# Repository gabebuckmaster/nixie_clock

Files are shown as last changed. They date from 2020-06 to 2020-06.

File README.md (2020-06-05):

# Nixie Tube Clock

<p align="center">
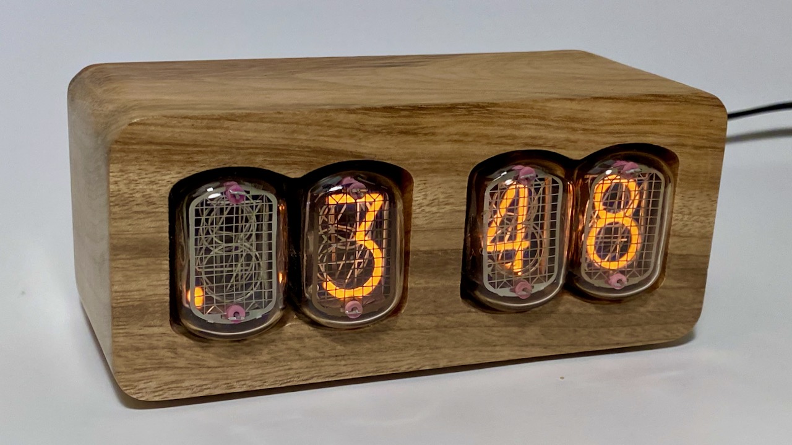
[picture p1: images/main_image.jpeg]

</p>

A minimalist nixie tube clock design in a cnc-machined hardwood case using IN12B tubes.

All of the design files and detailed assembly/compilation instructions for the electronics, mechanical components, and firmware can be found in the respective subfolders: <a href=electronics>Electronics</a>, <a href=mechanical>Mechanical</a>, and <a href=firmware>Firmware</a>. 

This design has gone through several iterations, mostly to simplify the design and remove extraneous features that I thought would be a good idea but ultimately weren't. While nixie tubes are beautiful, they objectively have some significant shortcomings as a display technology: their viewing angle is extremely limited, and they can't be dimmed to arbitrarily low brightnesses - not to mention the difficulty in working with the high voltages needed to drive them. Over the course of the project, the goal converged to showing off the beauty of nixie tubes with the minimum possible set of features, and I'm happy with how the final result aligns with this goal.

I learned a lot about cnc machining, and am left with a great respect for the people who do this for a living. An incredible amount of effort (and skill among those who practice this professionally) goes into simply clamping the work piece in a way that allows the router/mill the necessary access. I also learned a lot about boost converter design, specifically core losses, the huge range of magnetic core materials, and why power electronics people often advise against designing boost converters that operate in DCM.

## License and Disclaimer
I built this clock because I wanted it to exist, and I’m distributing the documentation in the hopes that others find it interesting and/or educational. To this end, the files provided in this repository are licensed under the MIT license unless otherwise noted a given file.

This design is not FCC, CE, or UL certified, and thus it is probably not legal nor advisable to sell this design as a finished product in your jurisdiction. This project involves potentially dangerous power tools, potentially lethal voltages, and potential fire hazard due to housing electronics in a flammable material. **If you choose to recreate any work documented in this repository, you do so entirely at your own risk.**

## Final Assembly
The bill of materials for the final assembly is in <a href="final_assembly_bom.csv">Final Assembly BOM</a>.

### Pseudo-exploded view of the final assembly
<p align="center">
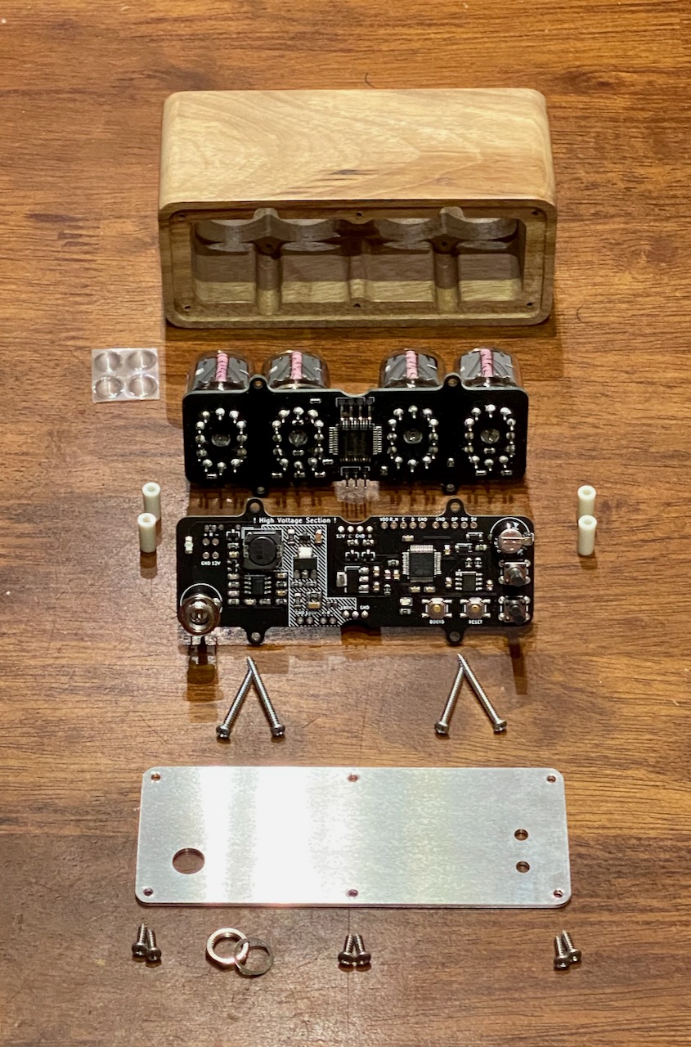
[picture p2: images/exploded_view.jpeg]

</p>

### Video of final assembly
<p align="center">
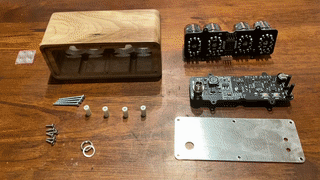
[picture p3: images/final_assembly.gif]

</p>
Click through for longer/higher resolution video of final assembly.

## More Photos
### Final Assembly
<p align="center">
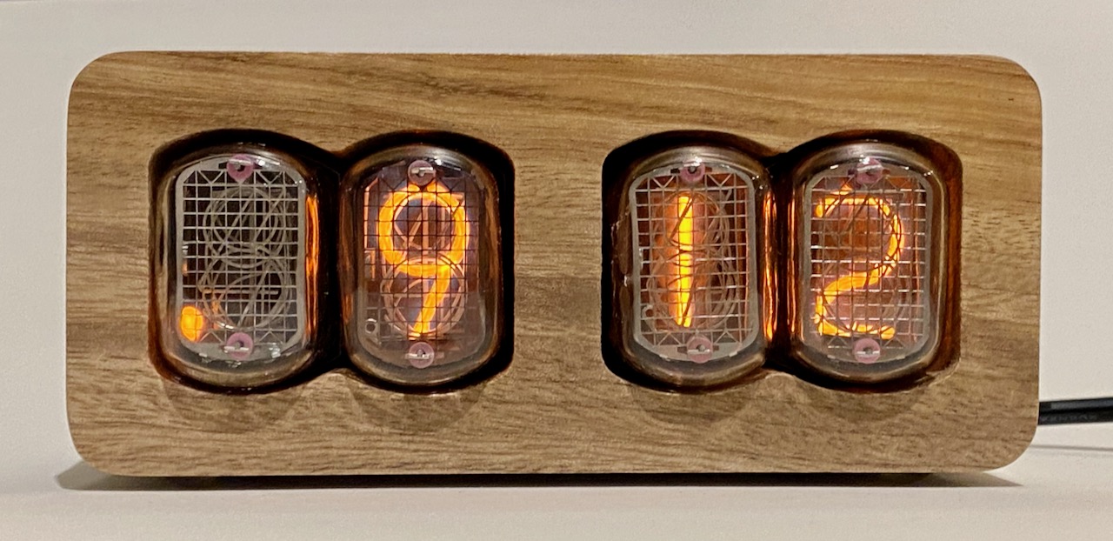
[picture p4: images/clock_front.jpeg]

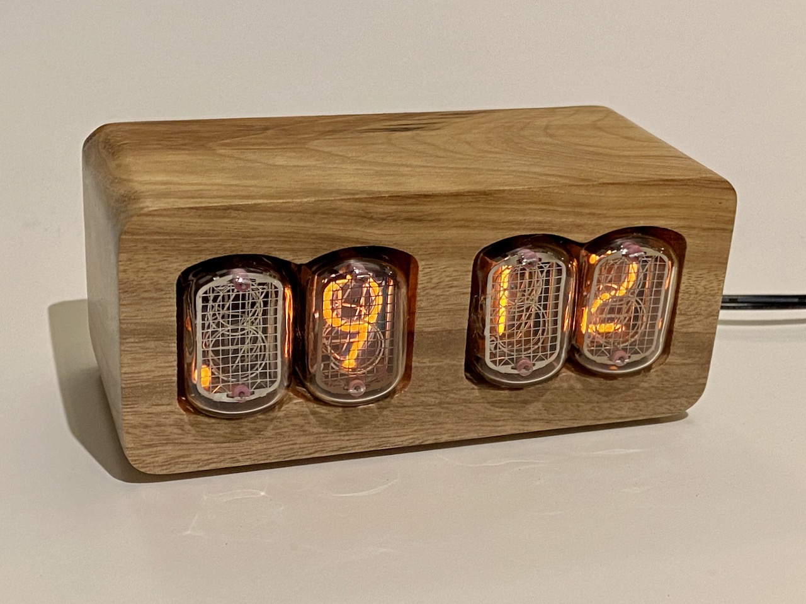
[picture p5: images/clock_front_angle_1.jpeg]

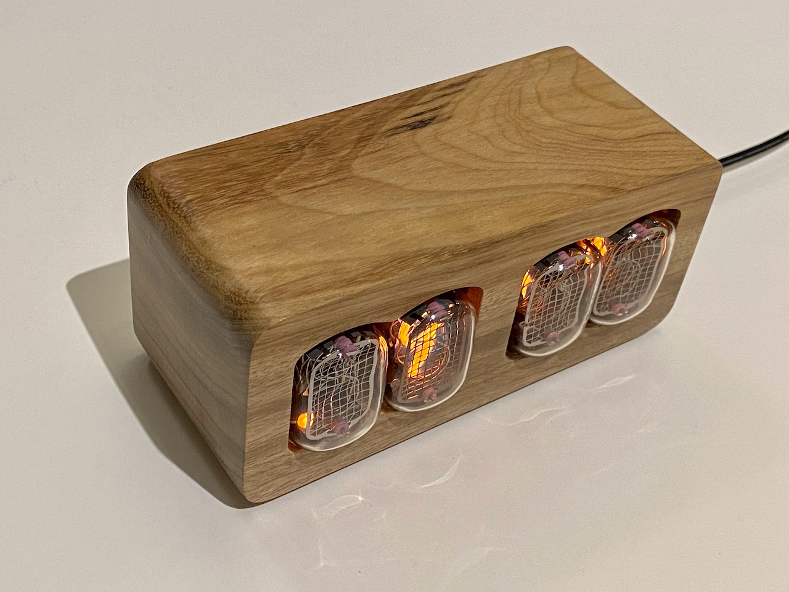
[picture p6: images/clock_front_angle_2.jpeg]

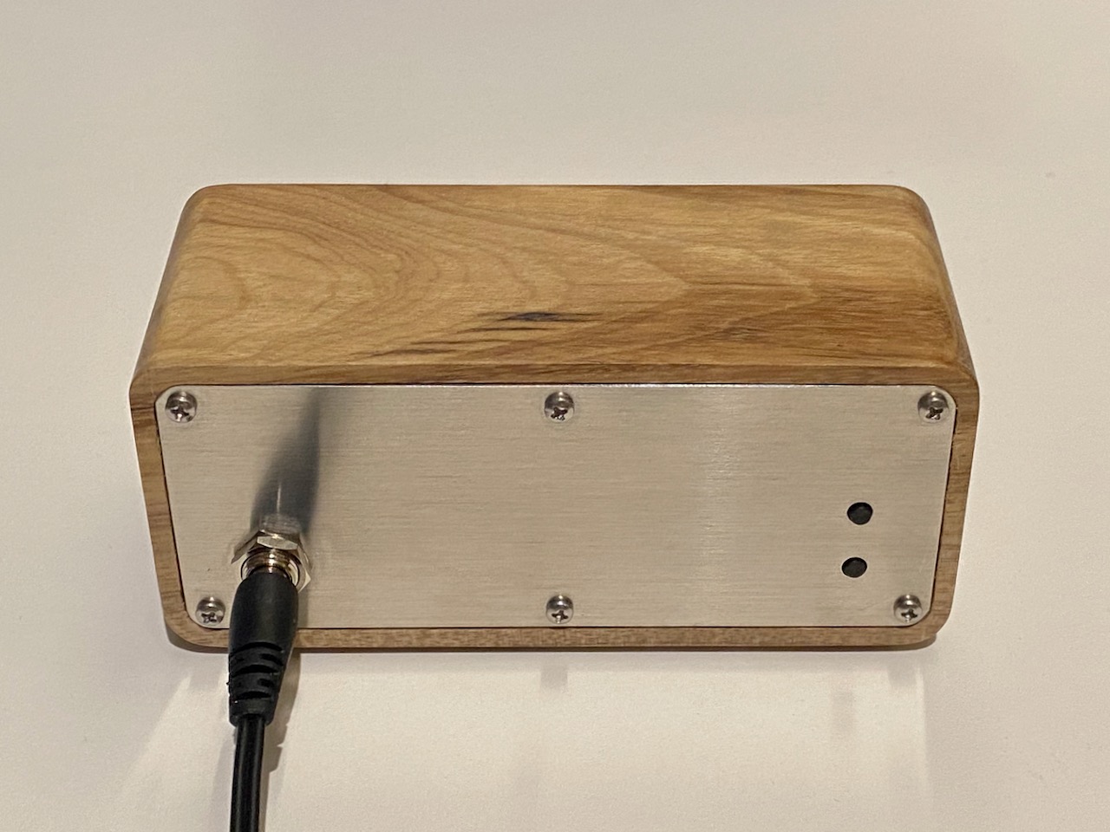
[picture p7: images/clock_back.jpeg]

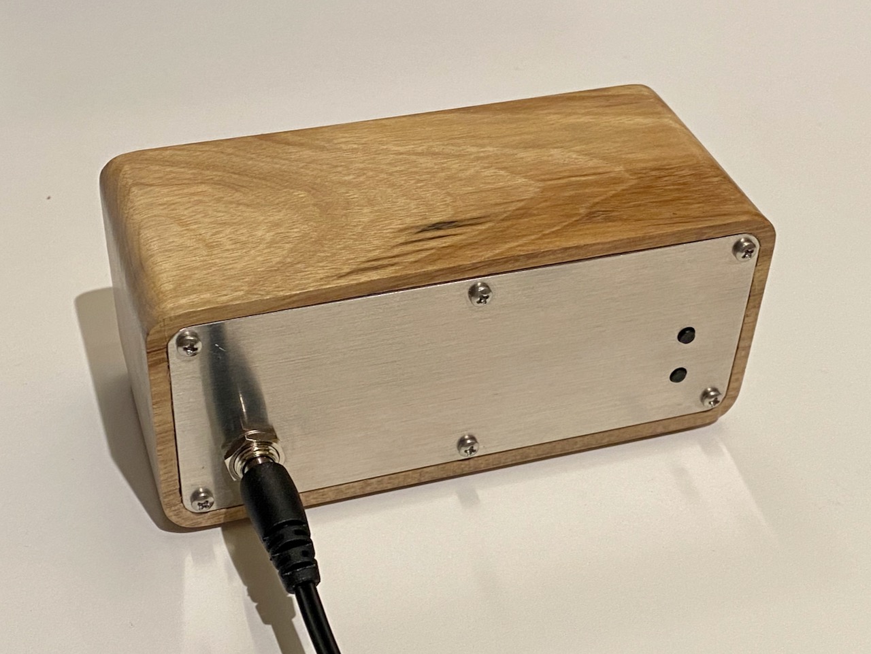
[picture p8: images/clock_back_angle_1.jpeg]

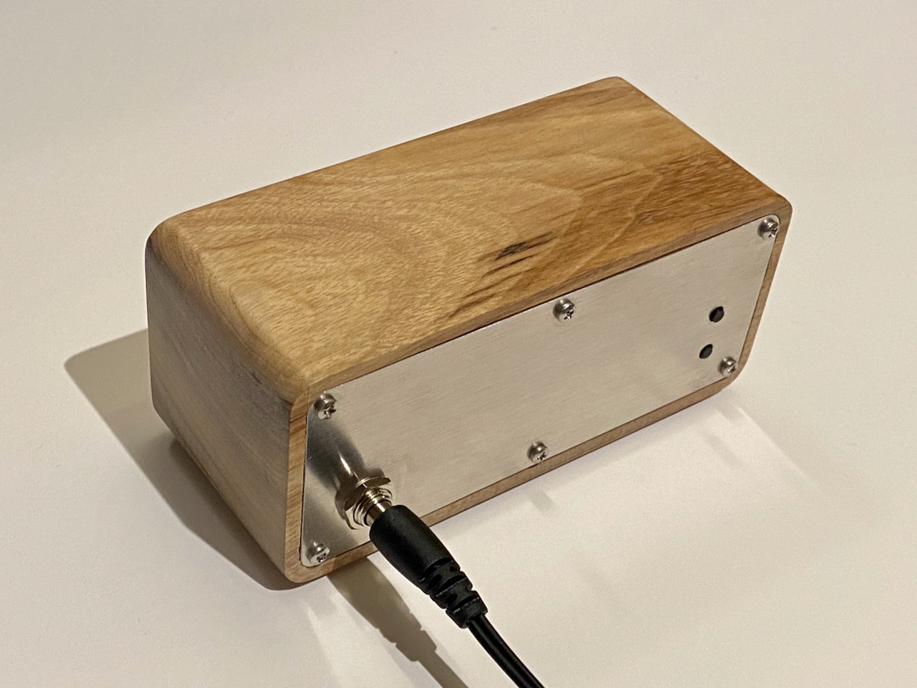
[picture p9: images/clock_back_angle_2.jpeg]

</p>

### Electronics
<p align="center">
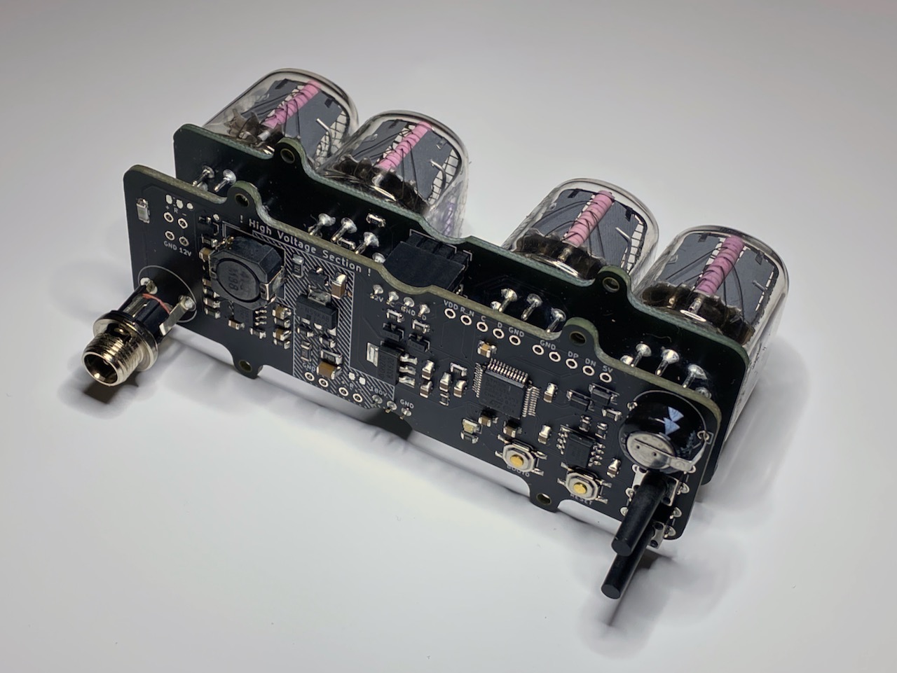
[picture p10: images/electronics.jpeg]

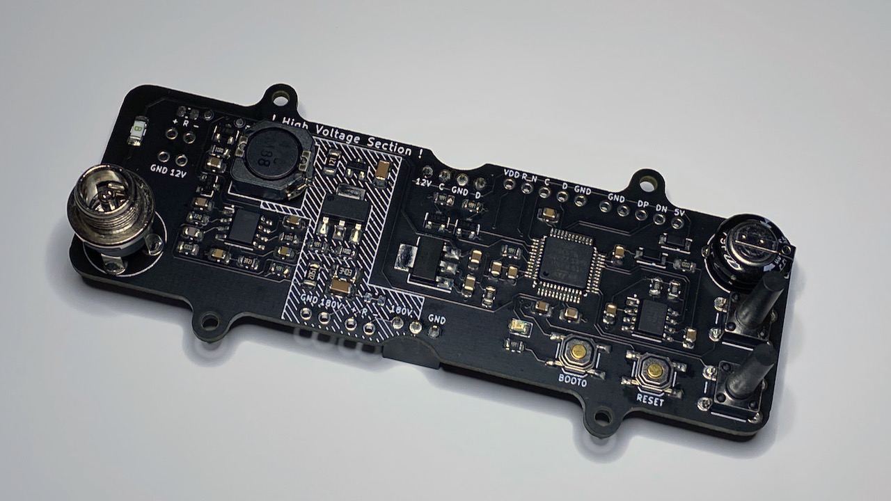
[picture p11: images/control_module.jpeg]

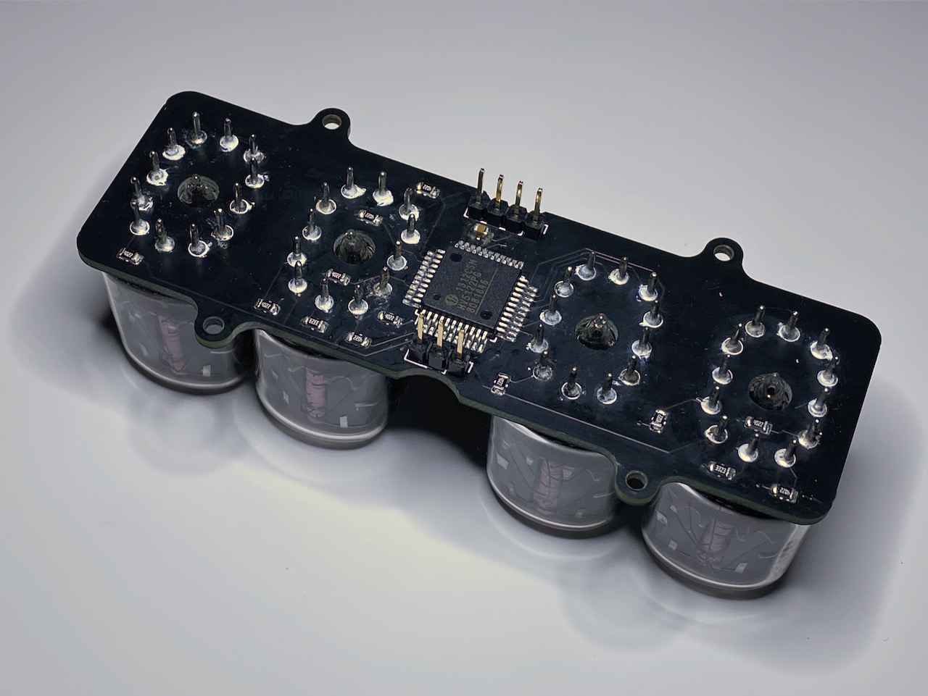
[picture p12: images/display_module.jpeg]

</p>

### Clock Body
<p align="center">
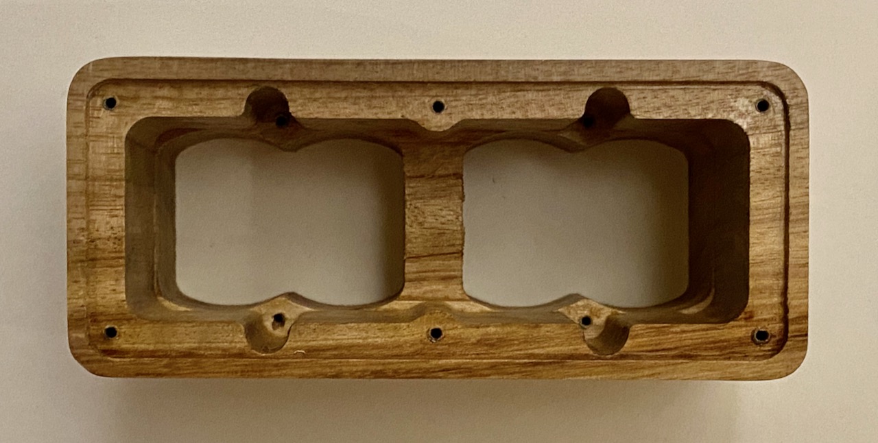
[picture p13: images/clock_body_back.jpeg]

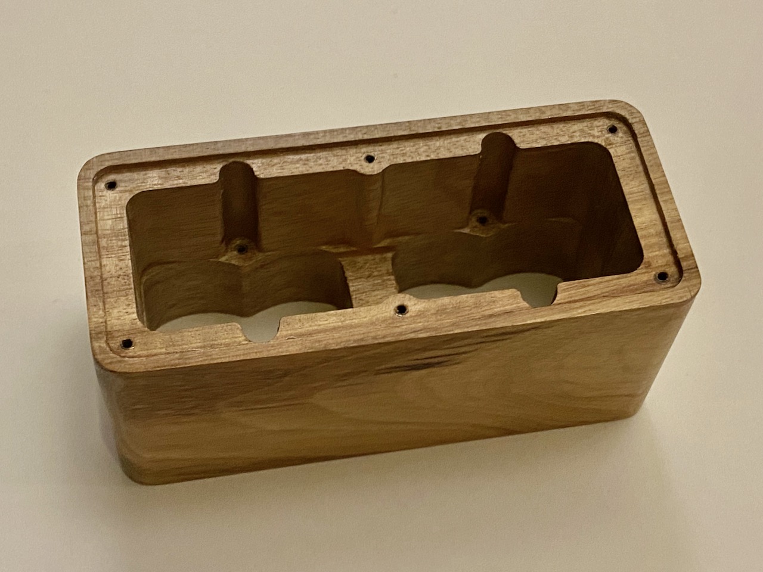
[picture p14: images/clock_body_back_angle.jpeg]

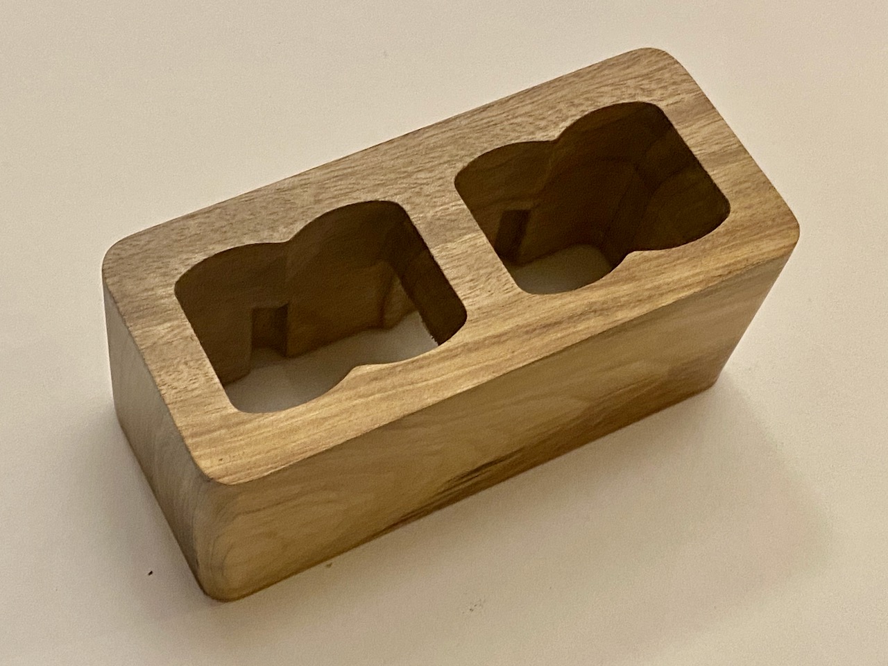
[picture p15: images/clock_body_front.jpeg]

</p>

### Back Panel
<p align="center">
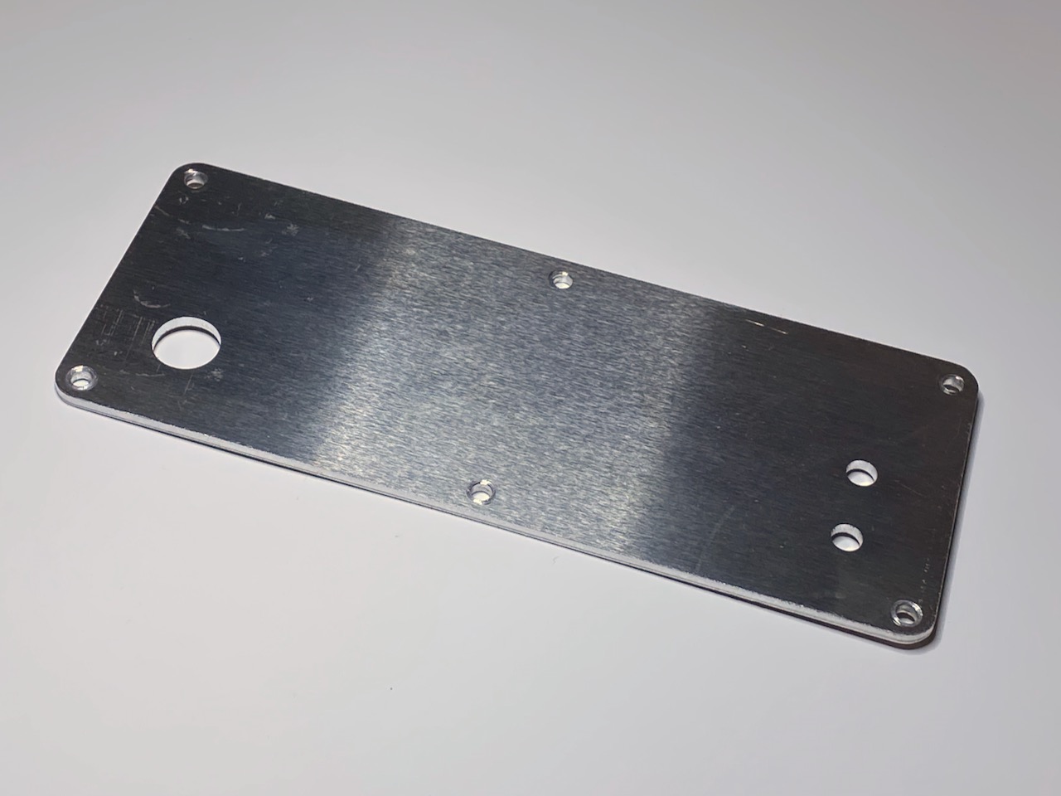
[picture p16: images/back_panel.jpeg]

</p>

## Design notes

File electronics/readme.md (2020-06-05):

# Electronics

<p align="center">

</p>

The electronics consist of two PCB assemblies. The control module runs the show and generates 180V for the nixie tubes, while the display module includes the nixie tubes and a high voltage shift register to drive them. The boards are interconnected with standard 0.1" headers. Everything is powered from an off-the-shelf 12V AC-DC adapter. 

Despite the 12V supply, the control module generates and the display module uses 180V at enough current to cause your heart to stop - don't work on this design unless you understand the risks and know how to safetly work on high voltage electronics. It was stated in the main readme, but is worth repeating here:  **If you choose to recreate any work documented in this repository, you do so entirely at your own risk.**

Both boards use 0805 passives and no leadless components for relatively pain-free hand soldering with nothing but a soldering iron, solder, and some flux! If you haven't done surface mount soldering before, don't let it scare you away. Surface mount soldering isn't as hard as it looks once you get the hang of it, and it opens up a whole new world of design opportunities.

Cleaning each board thoroughly after soldering and before powering up the board is critical, especially around the high voltage sections. This is true even if you use no-clean flux, which I found out the hard way after frying a couple $5 high-voltage shift registers.

## Control Module

<p align="center">

</p>

<a href="control_module/control_module.pdf">Schematic PDF</a>

This PCB includes the microcontroller, a temperature compensated real time clock IC with battery backup, and the boost converter that generates the 180V supply for the nixie tubes. 

The boost converter operates in DCM to achieve the 15x conversion ratio, and achieves ~70% efficency with widely available components at ~6mA output current. It includes a snubber to eliminate turn-off ringing at the drain of the switching mosfet. This slightly reduces overall efficiency, but improves output stability and might help reduce radiated EMI. The final value for the snubber resistance based on measurements (120 ohms) ended up being fairly different from the optimal value identified in simulation (300 ohms), indicating that there are probably some significant inaccuracies in the models used for simulation. However, the constructed converter is stable and tolerably efficient, so it's good enough for now.

For assembly, see the  <a href="control_module/control_module_bom.csv">BOM</a> and <a href="control_module/gerbers/control_module-F_Fab.pdf">fab drawing</a>

After assembly, the microcontroller must be programmed with the firmware. See the <a href=../firmware>firmware</a> folder for details.

### Through Hole Assembly Notes
* The 3- and 4-pin 0.1" pin header sockets (J3 and J4) must be mounted on the bottom side of the board (the opposite side from the surface mount components). I strongly recommend soldering only one pin on each socket first and verifying that the sockets are flush with and perpendicular to the board before soldering the rest of the pins.
* All other through hole components go on the top side of the board (the same side as the surface mount components).
* Make sure that the pushbuttons (SW1, SW2) and barrel jack (J5) are also installed flush with and perpendicular to the board so that final assembly goes smoothly.
* Make sure to observe the polarity of the supercapacitor C19 when installing.

## Display Module

<p align="center">

</p>

<a href="display_module/display_module.pdf">Schematic PDF</a>

This PCB includes the nixie tubes themselves, current limiting resistors, and the high voltage shift register. 

For assembly, see the  <a href="display_module/display_module_bom.csv">BOM</a> and <a href="display_module/gerbers/display_module-F_Fab.pdf">fab drawing</a>

### Through Hole Assembly Notes
* The tubes must be mounted on the bottom side of the board (the opposite side from the surface mount components).
* Aligning the tubes nicely is critical for the final appearance of the clock. There's a fairly large variation in the shape of the tubes themselves, so I strongly recommend soldering one pin on each tube and adjusting the position until they're nicely centered before soldering the rest of the pins. You can insert the display board into the clock body to verify tube positioning before soldering all of the pins.
* The 3- and 4-pin 0.1" headers go on the top side of the board (the same side as the surface mount components). A helpful trick for getting the best alignment is to insert the pin headers into the matching sockets on the control module to hold them in place while you're soldering them to the display module.

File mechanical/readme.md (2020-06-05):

# Mechanical Components

The mechanical components include the main body of the clock and the aluminum back panel. They were fabricated on a Shapeoko 3 cnc router as documented here and in the cad/cam files in the respective subfolders.

## Clock Body Fabrication

<p align="center">


</p>

I used a 3"x5"x5" Myrtle bowl blank from Cook Woods for this build, but have also had nice results with a Bocote blank from Woodcraft. Both were sold as green stock, but I haven't had any issues with splitting or deformation when I've applied polyurethane immediately after machining.

* Mount a wasteboard to the router. I simply screwed the wasteboard down with wood screws. Face the wasteboard if necessary.

* Face the stock (on both sides if necessary) to 50mm thick. These surfaces will form the front and back of the clock and should be fairly smooth.

* Cut the stock to ~55mm x ~121mm (2.5 mm beyond final dimensions on each side). 

* Mount the stock to the waste board using side clamps, leaving the entire top surface free for machining operations (Shop Fox D3347 is an economical option). Alternatively, use top clamps but be very careful about placement!

* Using a 1/4" square end mill with at least ~60mm exposure, zero the router on the center of the top face of the stock and run the "cavity_rough_and_finish" progam.



This video (click through to view) shows the main cavity machining operation. This operation takes about 38 minutes.

* Clamp the piece from the inside using a spare display circuit board and some wood screws (or make a custom jig to clamp the clock body from the inside). Make sure the display circuit board is centered, as the board will guide the drill bit in the drilling step later.
    * Alternatively, you may want to switch to the 1/16" drill bit and make the drills before switching the clamping method so that the internal clamping jig (a.k.a. spare display circuit board) doesn't guide the drill hit. 



This video (click through to view) shows the switch to internal clamping, allowing the router to shape the outer profile.

* Again using a 1/4" square end mill with at least ~60mm exposure, run the "outer_profile_roughing_and_finishing" program. 



This video (click through to view) shows the outer profile milling operation. This operation takes about 6 minutes.

* Switch to a 1/16" drill bit with ~50mm exposure. I cut a 1/16" x 6" long drill bit down to about 3", and used an ER-16 collet extender with 1/4" shank and 1/16" collet to hold the bit with acceptable runout. The drill chuck style holders that I tried were useless for this because of their terrible runout. It's a little sketchy to run such a long, skinny bit in a router, but at the lowest speed setting on my DWP-611 it worked fine. 



This video (click through to view) shows the drilling operation. This operation uses peck drilling for the relatively high aspect ratio drills and only takes about a minute.

* Lastly, finish as you see fit: I sanded to 300 grit and then finished with a matte polyurethane.

## Back Panel Fabrication

<p align="center">

</p>

* Mount a wasteboard to the router. As with the clock body, I screwed the wasteboard down with wood screws. Face the wasteboard if necessary.

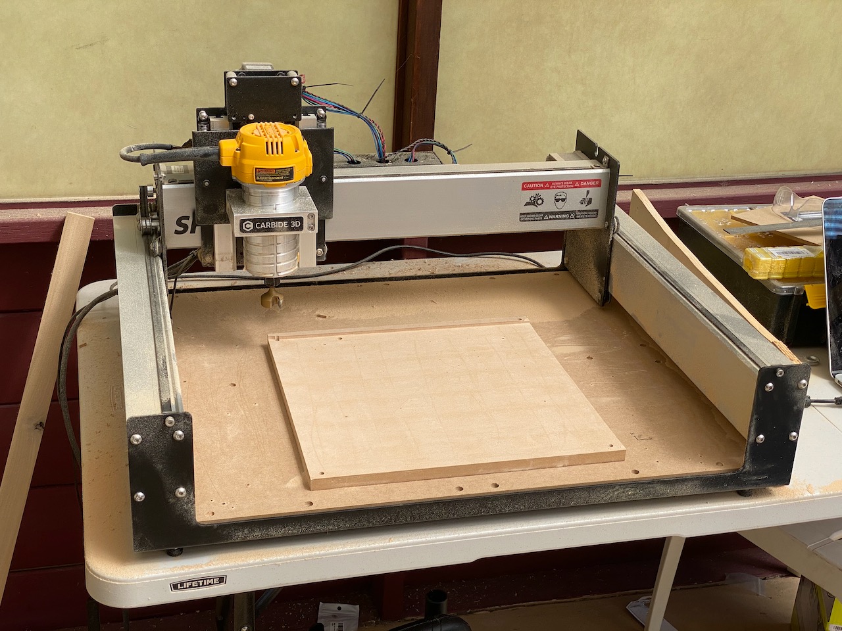
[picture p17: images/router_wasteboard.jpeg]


* Use double-sided tape to attach 1/16" 6061-T6 aluminum sheet to wasteboard. I strongly recommend against using 3003 aluminum, even if it's easier to find: I found it basically impossible to find feed rate and spindle speed settings that gave clean cuts in 3003 aluminum.
* Using a 2.5mm drill bit (#2 screw clearance hole) and the 1/4" to 1/8" collet reducer, set zeros and run the drills program. In all of the NC files I've created for this project, the origin is at the center of the top face of the stock.



This video (click through to view) shows the "3x" design on a 6"x6" sheet of aluminum. The drilling operation for the 3 back panels took ~45s.

* Attach aluminum sheet to wasteboard with back panel screws for a more secure mount.
* Using a 1/8" end mill and the 1/4" to 1/8" collet reducer, zero the Z axis only, and run the back panel milling program.



This video (click thorugh to view) shows the "3x" design on a 6"x6" sheet of aluminum. The milling operation for the 3 back panels took ~20m. 

* Finish the back panels as you see fit: I rounded the sharp outer edges with some sand paper and slightly chamfered the holes for the buttons by hand with a large drill bit.

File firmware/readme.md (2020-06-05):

# Firmware
The firmware is written using the [stm32duino core (8f53782b)](https://github.com/stm32duino/Arduino_Core_STM32) and [Adafruit's RTCLib 1.7.0](https://github.com/adafruit/RTClib). A custom board definition is used for the STM32F042C6T6 processor, which works for this application but has not been checked to be compatible with anything else.

To set up Arduino to compile for the STM32F042C6T6, perform the following steps:

* Install the stm32duino core

* Add the Generic_F042Cx folder to the variants folder in Arduino_Core_STM32.

* In boards.txt, under Generic F0, add:
```
# Generic STM32F042C6T8 board
GenF0.menu.pnum.Generic_F42C6=Generic STM32F042C6
GenF0.menu.pnum.Generic_F42C6.upload.maximum_size=32768
GenF0.menu.pnum.Generic_F42C6.upload.maximum_data_size=10240
GenF0.menu.pnum.Generic_F42C6.build.board=Generic_F042Cx
GenF0.menu.pnum.Generic_F42C6.build.product_line=STM32F042x6
GenF0.menu.pnum.Generic_F42C6.build.variant=Generic_F042Cx
```

Choose Sketch > Export compiled binary and flash to the controller board using STM32CubeProgrammer. You can use SWD (STLink V2 or similar, clones typically work fine and are only a couple of dollars) (tested) or USB DFU by carefully holding BOOT0 while resetting the board (untested). Extreme care should be taken when flashing the board due to the integrated high voltage supply.

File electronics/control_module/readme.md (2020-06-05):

# Control Module

<p align="center">

</p>

This PCB includes the microcontroller, a temperature compensated real time clock IC with battery backup, and the boost converter that generates the 180V supply for the nixie tubes.

For assembly, see the  <a href="control_module_bom.csv">BOM</a> and <a href="gerbers/control_module-F_Fab.pdf">fab drawing</a>

<a href="control_module.pdf">Schematic PDF</a>

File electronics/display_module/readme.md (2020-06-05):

# Display Module

<p align="center">

</p>

This PCB includes the nixie tubes themselves, current limiting resistors, and the high voltage shift register. 

For assembly, see the  <a href="display_module_bom.csv">BOM</a> and <a href="gerbers/display_module-F_Fab.pdf">fab drawing</a>

<a href="control_module.pdf">Schematic PDF</a>

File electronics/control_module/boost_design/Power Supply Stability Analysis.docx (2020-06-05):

Power Supply Stability Analysis

The wide range in small-signal output resistance makes compensation of the boost converter challenging.

For a simple voltage divider feedback with a minimum phase margin of 50 degrees over the load resistance range, the bandwidth for the high load resistance case was ~600 Hz. This corresponds to ~20V overshoot for a 10 mA step, which is a bit higher than I’d like.

Voltage Divider R1: 5000.0

Voltage Divider R2: 355000.0

### Maximum Rload ###

Crossover Frequency: 603.643850607587

Phase Margin: 89.53007430355954

### Minimum Rload ###

Crossover Frequency: 18891.927762076644

Phase Margin: 52.145191270698845

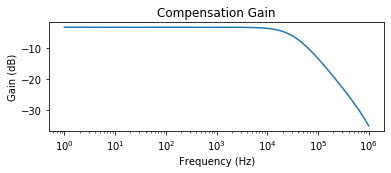
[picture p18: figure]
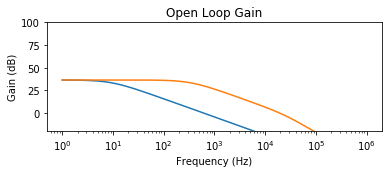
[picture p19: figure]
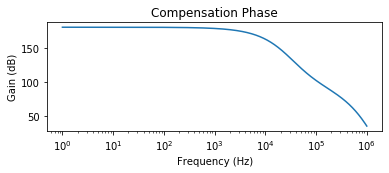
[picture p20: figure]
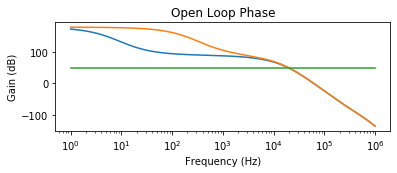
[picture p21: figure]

Adding a lead compensator (zero frequency < pole frequency) near the lowest pole frequency of the converter itself extends the bandwidth of the feedback loop. However, we have to reduce the gain of the error amplifier to make sure the error amplifier poles don’t cause any issues. The gain of the lead compensator is chosen to put at most ¼ Vout over the capacitor, allowing us to use common 100V capacitors. Lastly, an integrator is placed in the error amplifier feedback path to eliminate DC errors.

Voltage Divider R1: 5000.0

Voltage Divider R2: 355000.0

Voltage Divider R2a: 340000.0

Voltage Divider R2b: 15000.0

Voltage Divider C2a: 93.62055475993844 nF

Error Amplifier Rf (series): 22000.0

Error Amplifier Cf (series): 22.0 nF

### Maximum Rload ###

Crossover Frequency: 1333.8669479535445

Phase Margin: 80.50769880169565

### Minimum Rload ###

Crossover Frequency: 49189.13516317414

Phase Margin: 58.08831512340727

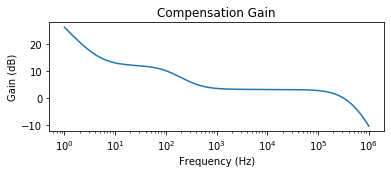
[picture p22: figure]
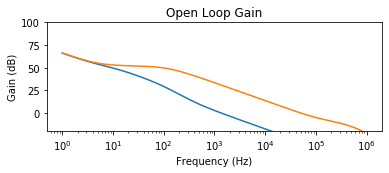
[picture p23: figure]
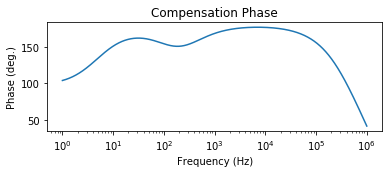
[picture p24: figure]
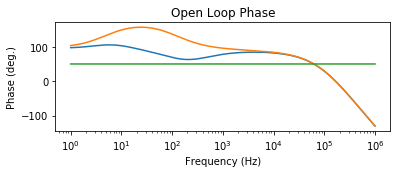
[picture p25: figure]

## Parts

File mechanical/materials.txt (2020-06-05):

Materials

Hardwood blank - at least ~60 mm x ~60 mm x ~125mm, Woodcraft, Cooks
Aluminum sheet 0.063" 6061-T6 - at least ~60mm x ~125mm, McMaster

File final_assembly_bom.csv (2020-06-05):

Quantity | Description | Manufacturer | MPN | Source
1 | Clock body (mechanical/clock_body)
1 | Back panel (mechanical/back_panel)
1 | Control module (electronics/control_module)
1 | Display module (electronics/display_module)
6 | #2 Sheet metal screws 5/16"
4 | #2 Sheet metal screws 1"
4 | #2 Nylon spacer 7/16" | Bivar Inc | 9913-437 | https://www.digikey.com/product-detail/en/bivar-inc/9913-437/492-1047-ND/586367
4 | Rubber feet clear 1/4" dia. x 0.075" tall | 3M | SJ5382 | https://www.digikey.com/product-detail/en/3m/SJ5382/SJ5382-ND/3866079
1 | 12V 5W AC adapter 5.5mm barrel jack output | XP Power | VEL05US120-US-JA | https://www.digikey.com/product-detail/en/xp-power/VEL05US120-US-JA/1470-2774-ND/5023716

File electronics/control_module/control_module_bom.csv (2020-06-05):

Reference(s) | Qty | Description | Value | Manufacturer | MPN | Notes
C1, C2, C3, C4, C5 | 5 | 100 nF Ceramic Capacitor X5R 25V 0805 | 100n | Generic
C6, C7, C8, C9 | 4 | 1 uF Ceramic Capacitor X5R 25V 0805 | 1u | Generic
C10, C11, C12, C13 | 4 | 10uF Ceramic Capacitor X5R 25V 0805 | 10u | Generic
C14, C15 | 2 | 100 nF Ceramic Capacitor 250V 1206 | 100n 250V | Generic
C16 | 1 | 22 nF Ceramic Capacitor 25V 0805 | 22n | Generic
C17 | 1 | 240 pF Ceramic Capacitor 25V 0805 | 240p | Generic
C18 | 1 | 2.2 nF Ceramic Capacitor 25V 0805 | 2.2nF | Generic
C19 | 1 | 330 mF Supercapacitor 5.5V 10mm Dia. | 330mF | Elna | DX-5R5H334U
D1 | 1 | Schottky Diode (Dual) 400 mA 240V SOT23 |  | Infineon | BAT240AE6327HTSA1
D2, D3 | 2 | Schottky Diode 200 mA 30V SOD123 |  | ON Semiconductor | BAT54T1G
D4 | 1 | Green LED 0805 |  | Generic
F1 | 1 | 250 mA Surface Mount Fuse 1206 | 250 mA | Generic
J1, J2 | 2 | 0.1" Header Footprint | NO STUFF (programming ports)
J3 | 1 | 0.1" Female Header 1x3 TH |  | Generic
J4 | 1 | 0.1" Female Header 1x4 TH |  | Generic
J5 | 1 | Barrel Jack, 2mmx5.5mm TH |  | CUI | PJ-064A
J101, J102, J103, J104 | 4 | 0.1" Header Footprint | NO STUFF (efficiency measurement)
L1 | 1 | 47uH Inductor 2.3A 10.5mm x 10.3mm SMD | 47u | Sumida | CDRH105RNP-470NC
Q1, Q2, Q3 | 3 | N MOSFET 60V 115 mA SOT23 | 2N7002 | Generic
Q4 | 1 | P MOSFET 50V 130 mA SOT23 | BSS84 | Generic
Q5 | 1 | N MOSFET 250V 790 mA SOT223 | IRFL214 | Vishay Siliconix | IRFL214TRPBF
R1, R2, R3, R4, R5, R6, R7, R8 | 8 | Resistor 1% 0805 | 4.99k | Generic
R9 | 1 | Resistor 1% 0805 | 4.99k 1% | Generic
R10 | 1 | Resistor 1% 0805 | 1 1% | Generic
R11, R12 | 2 | Resistor 1% 0805 | 10 | Generic
R13, R14 | 2 | Resistor 1% 0805 | 100 | Generic
R16 | 1 | Resistor 1% 0805 | 3.92k 1% | Generic
R17 | 1 | Resistor 1% 0805 | 22.1k 1% | Generic
R18 | 1 | Resistor 1% 1206 | 15k 1% | Generic
R19 | 1 | Resistor 1% 1206 | 340k 1% | Generic
R20 | 1 | Resistor 5% 1206 | 120 1/4W | Generic
R101, R102 | 2 | Resistor 0805 | NO STUFF (efficiency measurement)
SW1, SW2 | 2 | Tactile Pushbutton 6mmx6mmx15mm TH |  | Generic
SW3, SW4 | 2 | Tactile Pushbutton 5.2mmx5.2mm SMD |  | Generic | Ex: Shou Han TS5215A
U1 | 1 | Microcontroller QFP-48 |  | STMicroelectronics | STM32F042C6T6
U2 | 1 | Switching Regualtor Controller SOIC-8 |  | ON Semiconductor | UC3843BD1G
U3 | 1 | 3.3V LDO SOT223 |  | Diodes Inc | AZ1117EH-3.3
U4 | 1 | Real Time Clock/TCXO SOIC-8 |  | Maxim Integrated | DS3231MZ | DS3232MZ should be a functional equivalent (unverified)

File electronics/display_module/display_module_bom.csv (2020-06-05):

Reference(s) | Qty | Description | Value | Manufacturer | MPN
C1 | 1 | 1 uF Ceramic Capacitor X5R 25V 0805 | 1u | Generic
DISP1, DISP2, DISP3, DISP4 | 4 | IN12B Nixie Tube
J1 | 1 | 0.1" Male Pin Header 1x3 TH |  | Generic
J2 | 1 | 0.1" Male Pin Header 1x4 TH |  | Generic
R1, R2, R3, R4, R5, R6, R7, R8, R9, R10, R11 | 11 | 1% Resistor 0805 | 40.2k
R12, R13 | 2 | 1% Resistor 0805 | 332k
U1 | 1 | High Voltage Shift Register |  | Microchip | HV5122

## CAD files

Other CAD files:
mechanical/back_panel/Back Panel 3x.f3d
mechanical/back_panel/Back Panel.f3d
mechanical/clock_body/Main Clock Body.f3d

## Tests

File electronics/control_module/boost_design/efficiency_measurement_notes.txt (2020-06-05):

With Pulse Electronics PF0560.473NLT inductor, IRFL214 switching mosfet, and 120 ohm snubber resistance:

Output: 5.14 mA at 182 V to display. 0.5 mA in feedback network
Input to boost converter: 133 mA at 12V. ~13 mA to controller.

Efficiency (power conversion only): 71%
Efficiency (with feedback/controller): 59%

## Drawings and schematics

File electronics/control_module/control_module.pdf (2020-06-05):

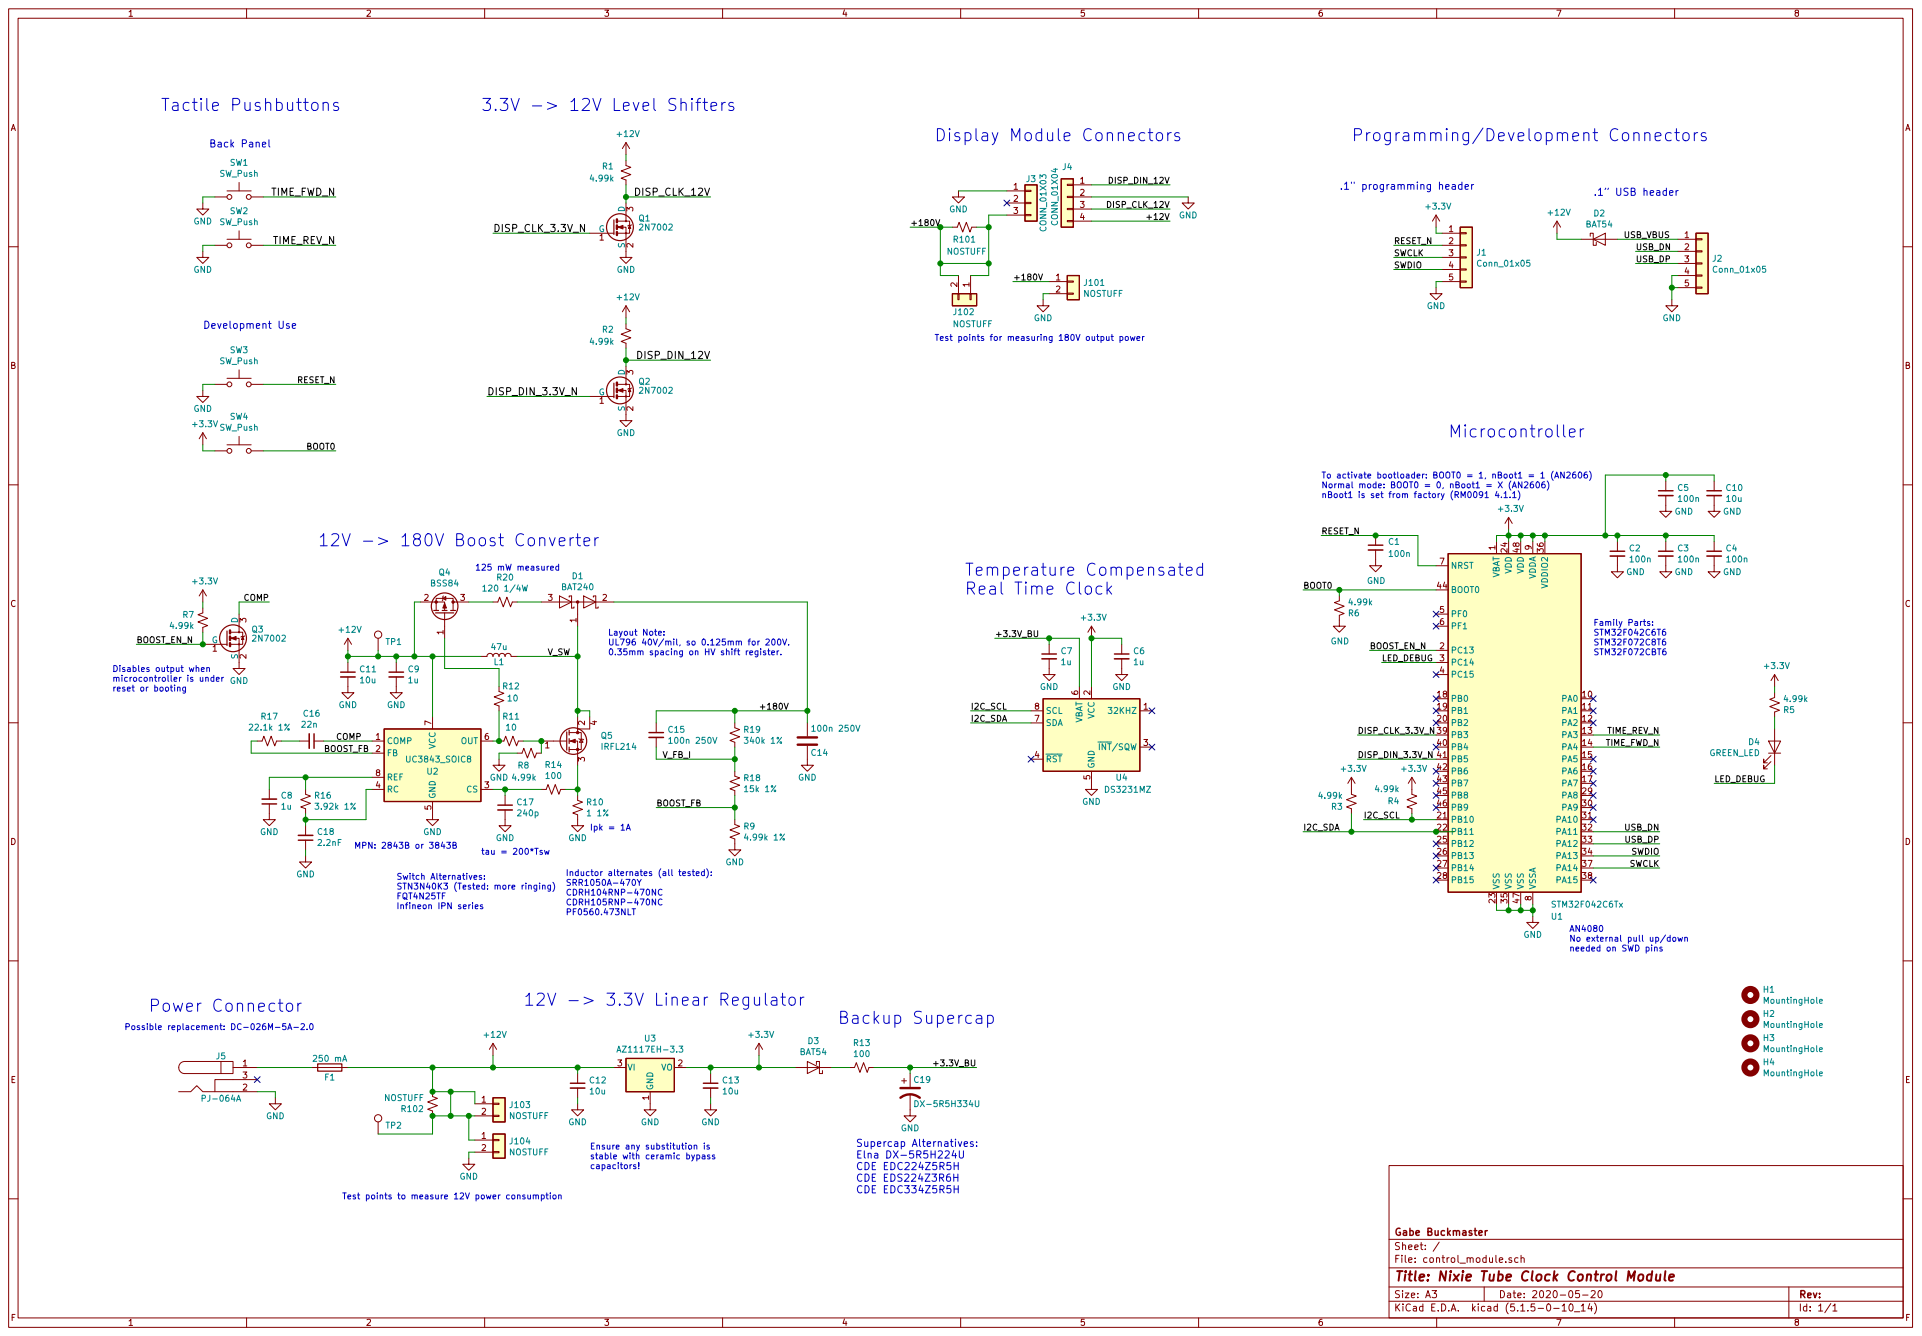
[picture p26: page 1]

Family Parts: STM32F042C6T6 STM32F072C8T6 STM32F072CBT6 Development Use

Test points for measuring 180V output power

To activate bootloader: BOOT0 = 1, nBoot1 = 1 (AN2606)
Normal mode: BOOT0 = 0, nBoot1 = X (AN2606)
nBoot1 is set from factory (RM0091 4.1.1)

1 PA0 10 PA1 11 PA2 12 PA3 13 PA4 14 PA5 15 PA6 16 PA7 17 PB0 18 PB1 19 PC13 2 PB2 20 PB10 21 PB11 22 VSS 23 VDD 24 PB12 25 PB13 26 PB14 27 PB15 28 PA8 29 PC14 3 PA9 30 PA10 31 PA11 32 PA12 33 PA13 34 VSS 35 VDDIO2 36 PA14 37 PA15 38 PB3 39 PC15 4 PB4 40 PB5 41 PB6 42 PB7 43 BOOT0 44 PB8 45 PB9 46 VSS 47 VDD 48 PF0 5 PF1 6 NRST 7 VSSA

Layout Note: UL796 40V/mil, so 0.125mm for 200V. 0.35mm spacing on HV shift register.

Disables output when microcontroller is under reset or booting

PF0560.473NLT MPN: 2843B or 3843B Power Connector

Switch Alternatives: STN3N40K3 (Tested: more ringing) FQT4N25TF

Inductor alternates (all tested): SRR1050A-470Y CDRH104RNP-470NC

needed on SWD pins

Ensure any substitution is
stable with ceramic bypass
capacitors!

Supercap Alternatives: Elna DX-5R5H224U

File: control_module.sch Sheet: / Gabe Buckmaster

Id: 1/1 Title: Nixie Tube Clock Control Module

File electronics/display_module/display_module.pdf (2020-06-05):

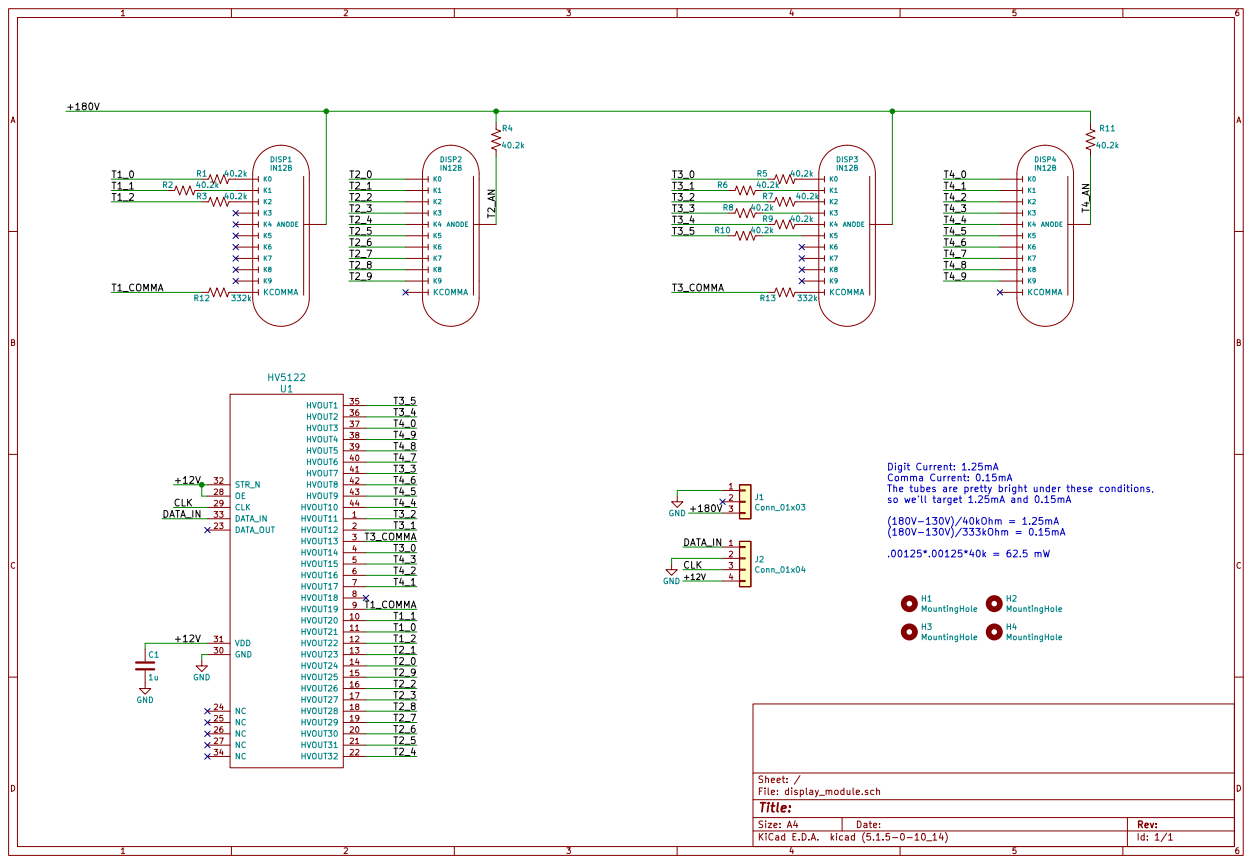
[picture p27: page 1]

Digit Current: 1.25mA
Comma Current: 0.15mA
The tubes are pretty bright under these conditions,
so well target 1.25mA and 0.15mA

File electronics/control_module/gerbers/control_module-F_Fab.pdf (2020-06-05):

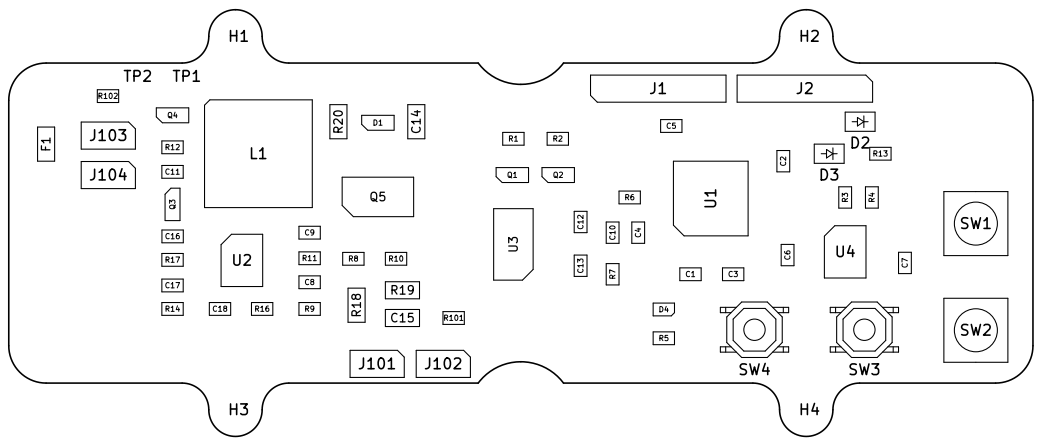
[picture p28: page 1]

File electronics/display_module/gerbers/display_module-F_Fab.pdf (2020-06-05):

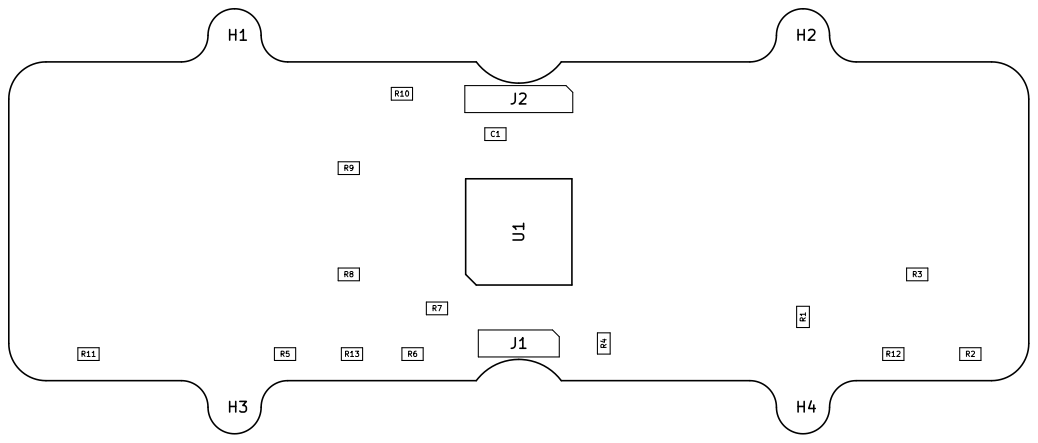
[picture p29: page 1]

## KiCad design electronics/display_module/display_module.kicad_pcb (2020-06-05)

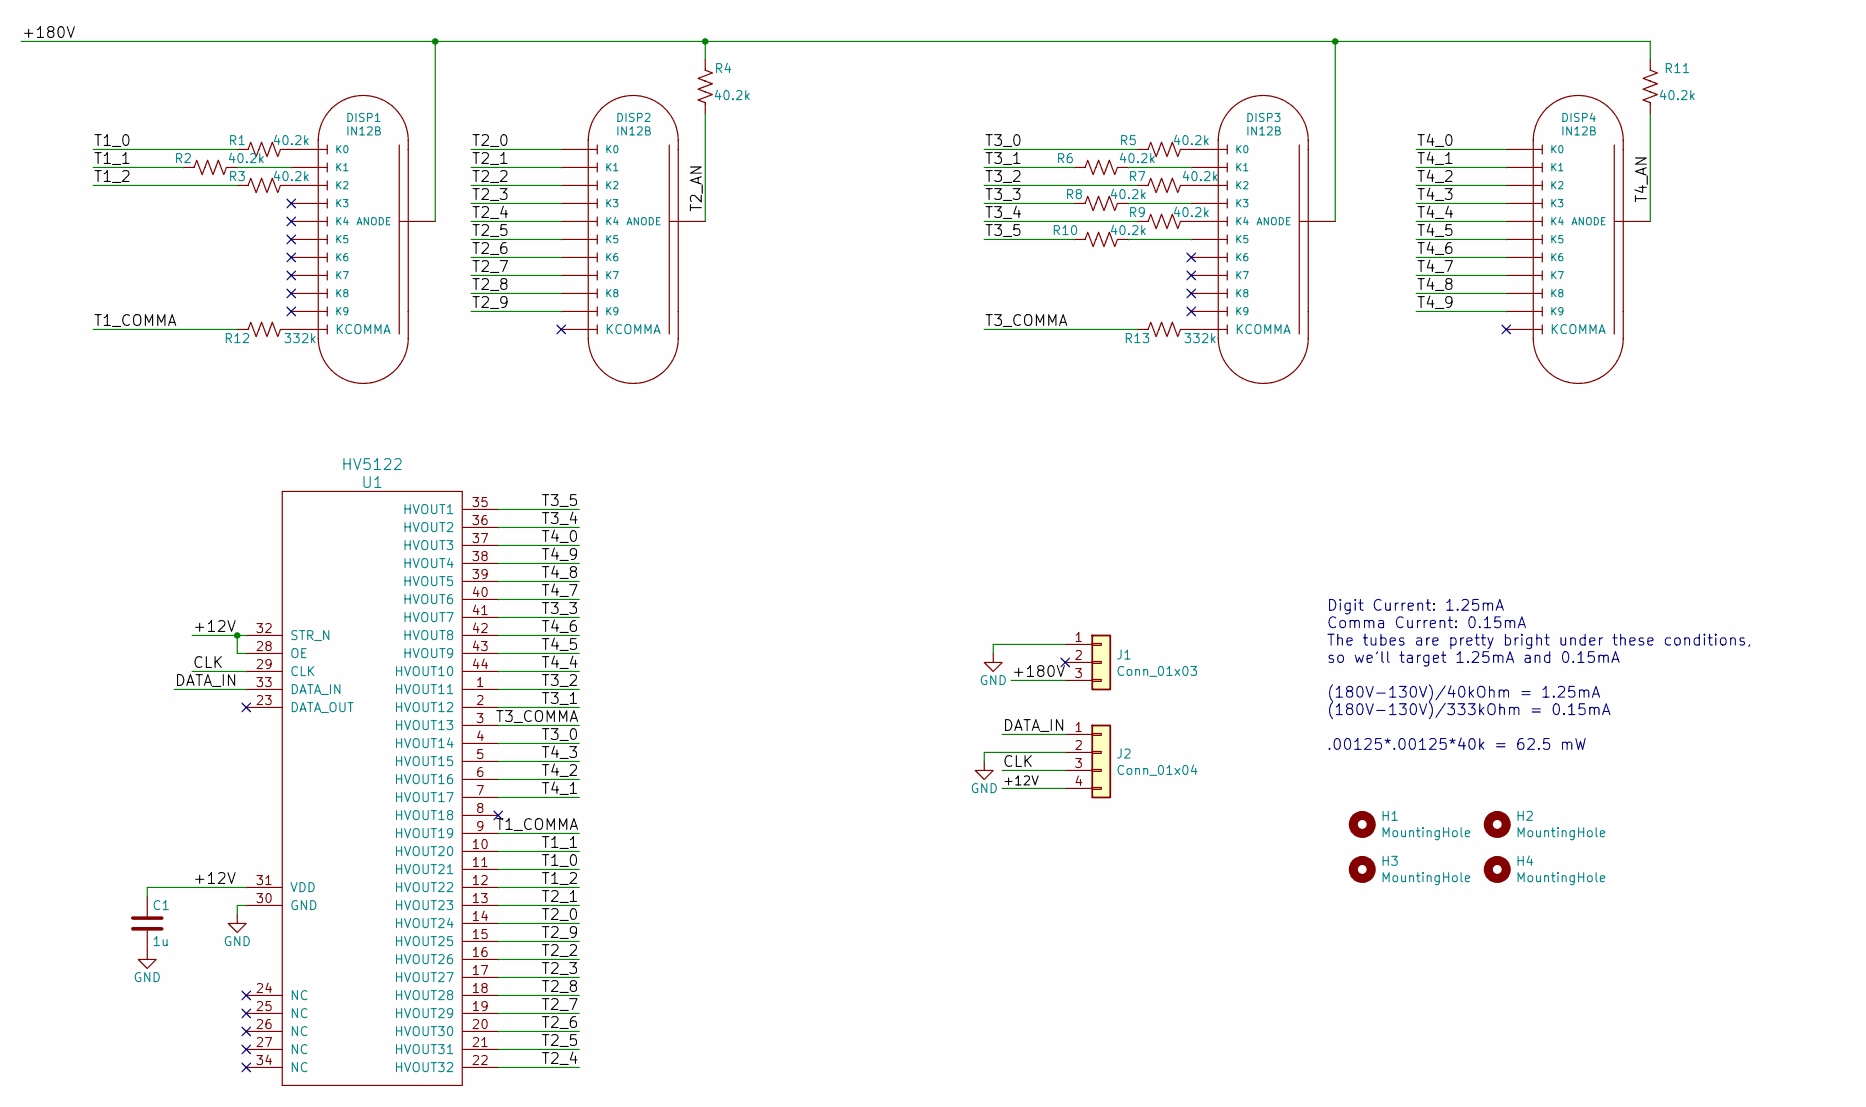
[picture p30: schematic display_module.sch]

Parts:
C1: 1u; C_0805_2012Metric
DISP1, DISP2, DISP3, DISP4: IN12B; IN-12B_nosocket
H1, H2, H3, H4: MountingHole; MountingHole_2.2mm_M2
J1: Conn_01x03; PinHeader_1x03_P2.54mm_Vertical
J2: Conn_01x04; PinHeader_1x04_P2.54mm_Vertical
R1, R2, R3, R4, R5, R6, R7, R8, R9, R10, R11: 40.2k; R_0805_2012Metric
R12, R13: 332k; R_0805_2012Metric
U1: HV5122; PQFP-44_10x10mm_Pitch0.8mm

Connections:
/+12V: C1.1, J2.4, U1.28 (OE), U1.31 (VDD), U1.32 (STR_N)
/+180V: DISP1.1 (ANODE), DISP3.1 (ANODE), J1.3, R4.1, R11.1
/CLK: J2.3, U1.29 (CLK)
/DATA_IN: J2.1, U1.33 (DATA_IN)
/T1_0: R1.2, U1.11 (HVOUT21)
/T1_1: R2.2, U1.10 (HVOUT20)
/T1_2: R3.2, U1.12 (HVOUT22)
/T1_COMMA: R12.2, U1.9 (HVOUT19)
/T2_0: DISP2.2 (K0), U1.14 (HVOUT24)
/T2_1: DISP2.11 (K1), U1.13 (HVOUT23)
/T2_2: DISP2.10 (K2), U1.16 (HVOUT26)
/T2_3: DISP2.9 (K3), U1.17 (HVOUT27)
/T2_4: DISP2.8 (K4), U1.22 (HVOUT32)
/T2_5: DISP2.7 (K5), U1.21 (HVOUT31)
/T2_6: DISP2.6 (K6), U1.20 (HVOUT30)
/T2_7: DISP2.5 (K7), U1.19 (HVOUT29)
/T2_8: DISP2.4 (K8), U1.18 (HVOUT28)
/T2_9: DISP2.3 (K9), U1.15 (HVOUT25)
/T2_AN: DISP2.1 (ANODE), R4.2
/T3_0: R5.2, U1.4 (HVOUT14)
/T3_1: R6.2, U1.2 (HVOUT12)
/T3_2: R7.2, U1.1 (HVOUT11)
/T3_3: R8.2, U1.41 (HVOUT7)
/T3_4: R9.2, U1.36 (HVOUT2)
/T3_5: R10.2, U1.35 (HVOUT1)
/T3_COMMA: R13.2, U1.3 (HVOUT13)
/T4_0: DISP4.2 (K0), U1.37 (HVOUT3)
/T4_1: DISP4.11 (K1), U1.7 (HVOUT17)
/T4_2: DISP4.10 (K2), U1.6 (HVOUT16)
/T4_3: DISP4.9 (K3), U1.5 (HVOUT15)
/T4_4: DISP4.8 (K4), U1.44 (HVOUT10)
/T4_5: DISP4.7 (K5), U1.43 (HVOUT9)
/T4_6: DISP4.6 (K6), U1.42 (HVOUT8)
/T4_7: DISP4.5 (K7), U1.40 (HVOUT6)
/T4_8: DISP4.4 (K8), U1.39 (HVOUT5)
/T4_9: DISP4.3 (K9), U1.38 (HVOUT4)
/T4_AN: DISP4.1 (ANODE), R11.2
GND: C1.2, J1.1, J2.2, U1.30 (GND)
unnamed: DISP1.2 (K0), R1.1
unnamed: DISP1.10 (K2), R3.1
unnamed: DISP1.11 (K1), R2.1
unnamed: DISP1.12 (KCOMMA), R12.1
unnamed: DISP3.2 (K0), R5.1
unnamed: DISP3.7 (K5), R10.1
unnamed: DISP3.8 (K4), R9.1
unnamed: DISP3.9 (K3), R8.1
unnamed: DISP3.10 (K2), R7.1
unnamed: DISP3.11 (K1), R6.1
unnamed: DISP3.12 (KCOMMA), R13.1

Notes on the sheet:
Digit Current: 1.25mA Comma Current: 0.15mA The tubes are pretty bright under these conditions, so we’ll target 1.25mA and 0.15mA (180V-130V)/40kOhm = 1.25mA (180V-130V)/333kOhm = 0.15mA .00125*.00125*40k = 62.5 mW

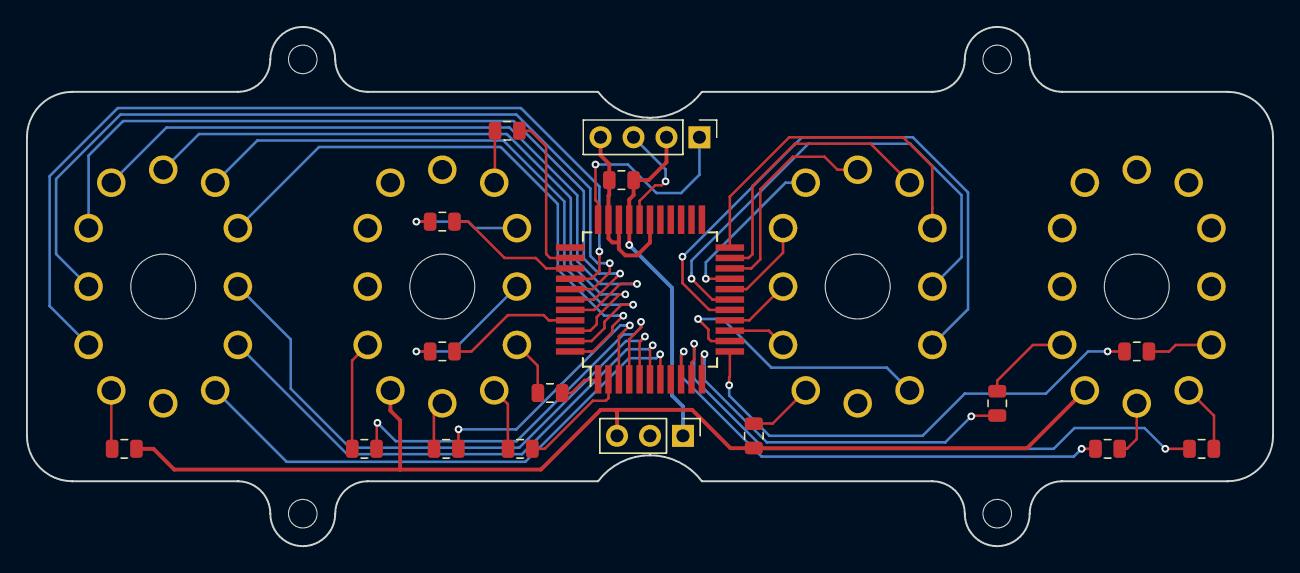
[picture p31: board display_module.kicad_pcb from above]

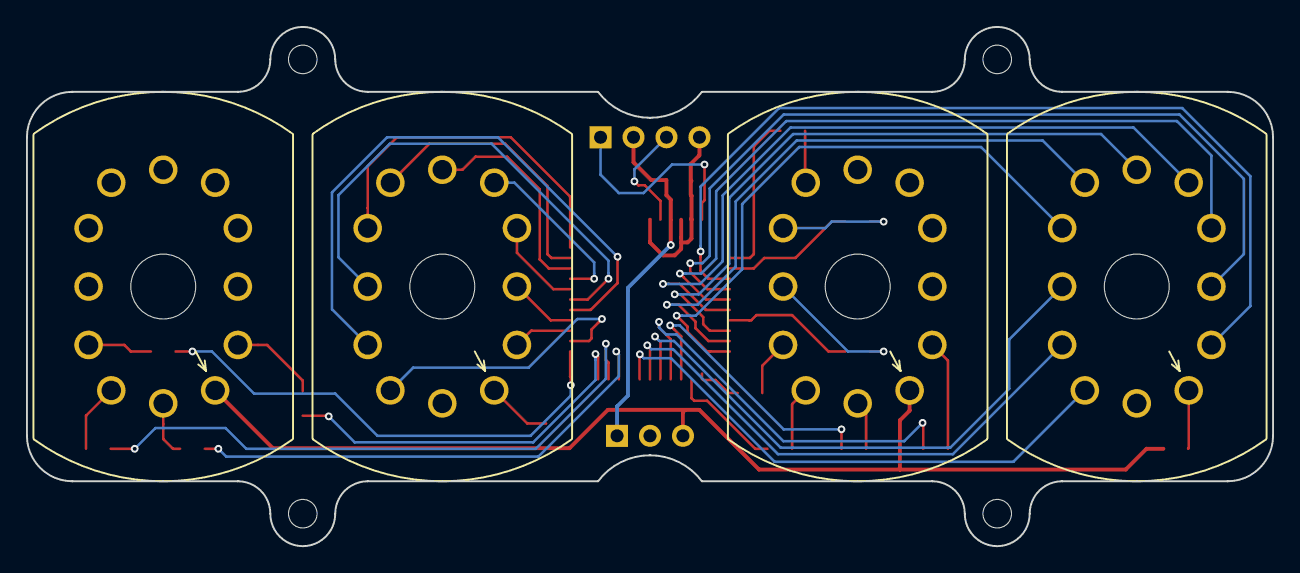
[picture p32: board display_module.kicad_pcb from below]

Board: 2 copper layers, 96.0 x 40.0 mm, 25 parts (4 on the bottom side), 49 nets.

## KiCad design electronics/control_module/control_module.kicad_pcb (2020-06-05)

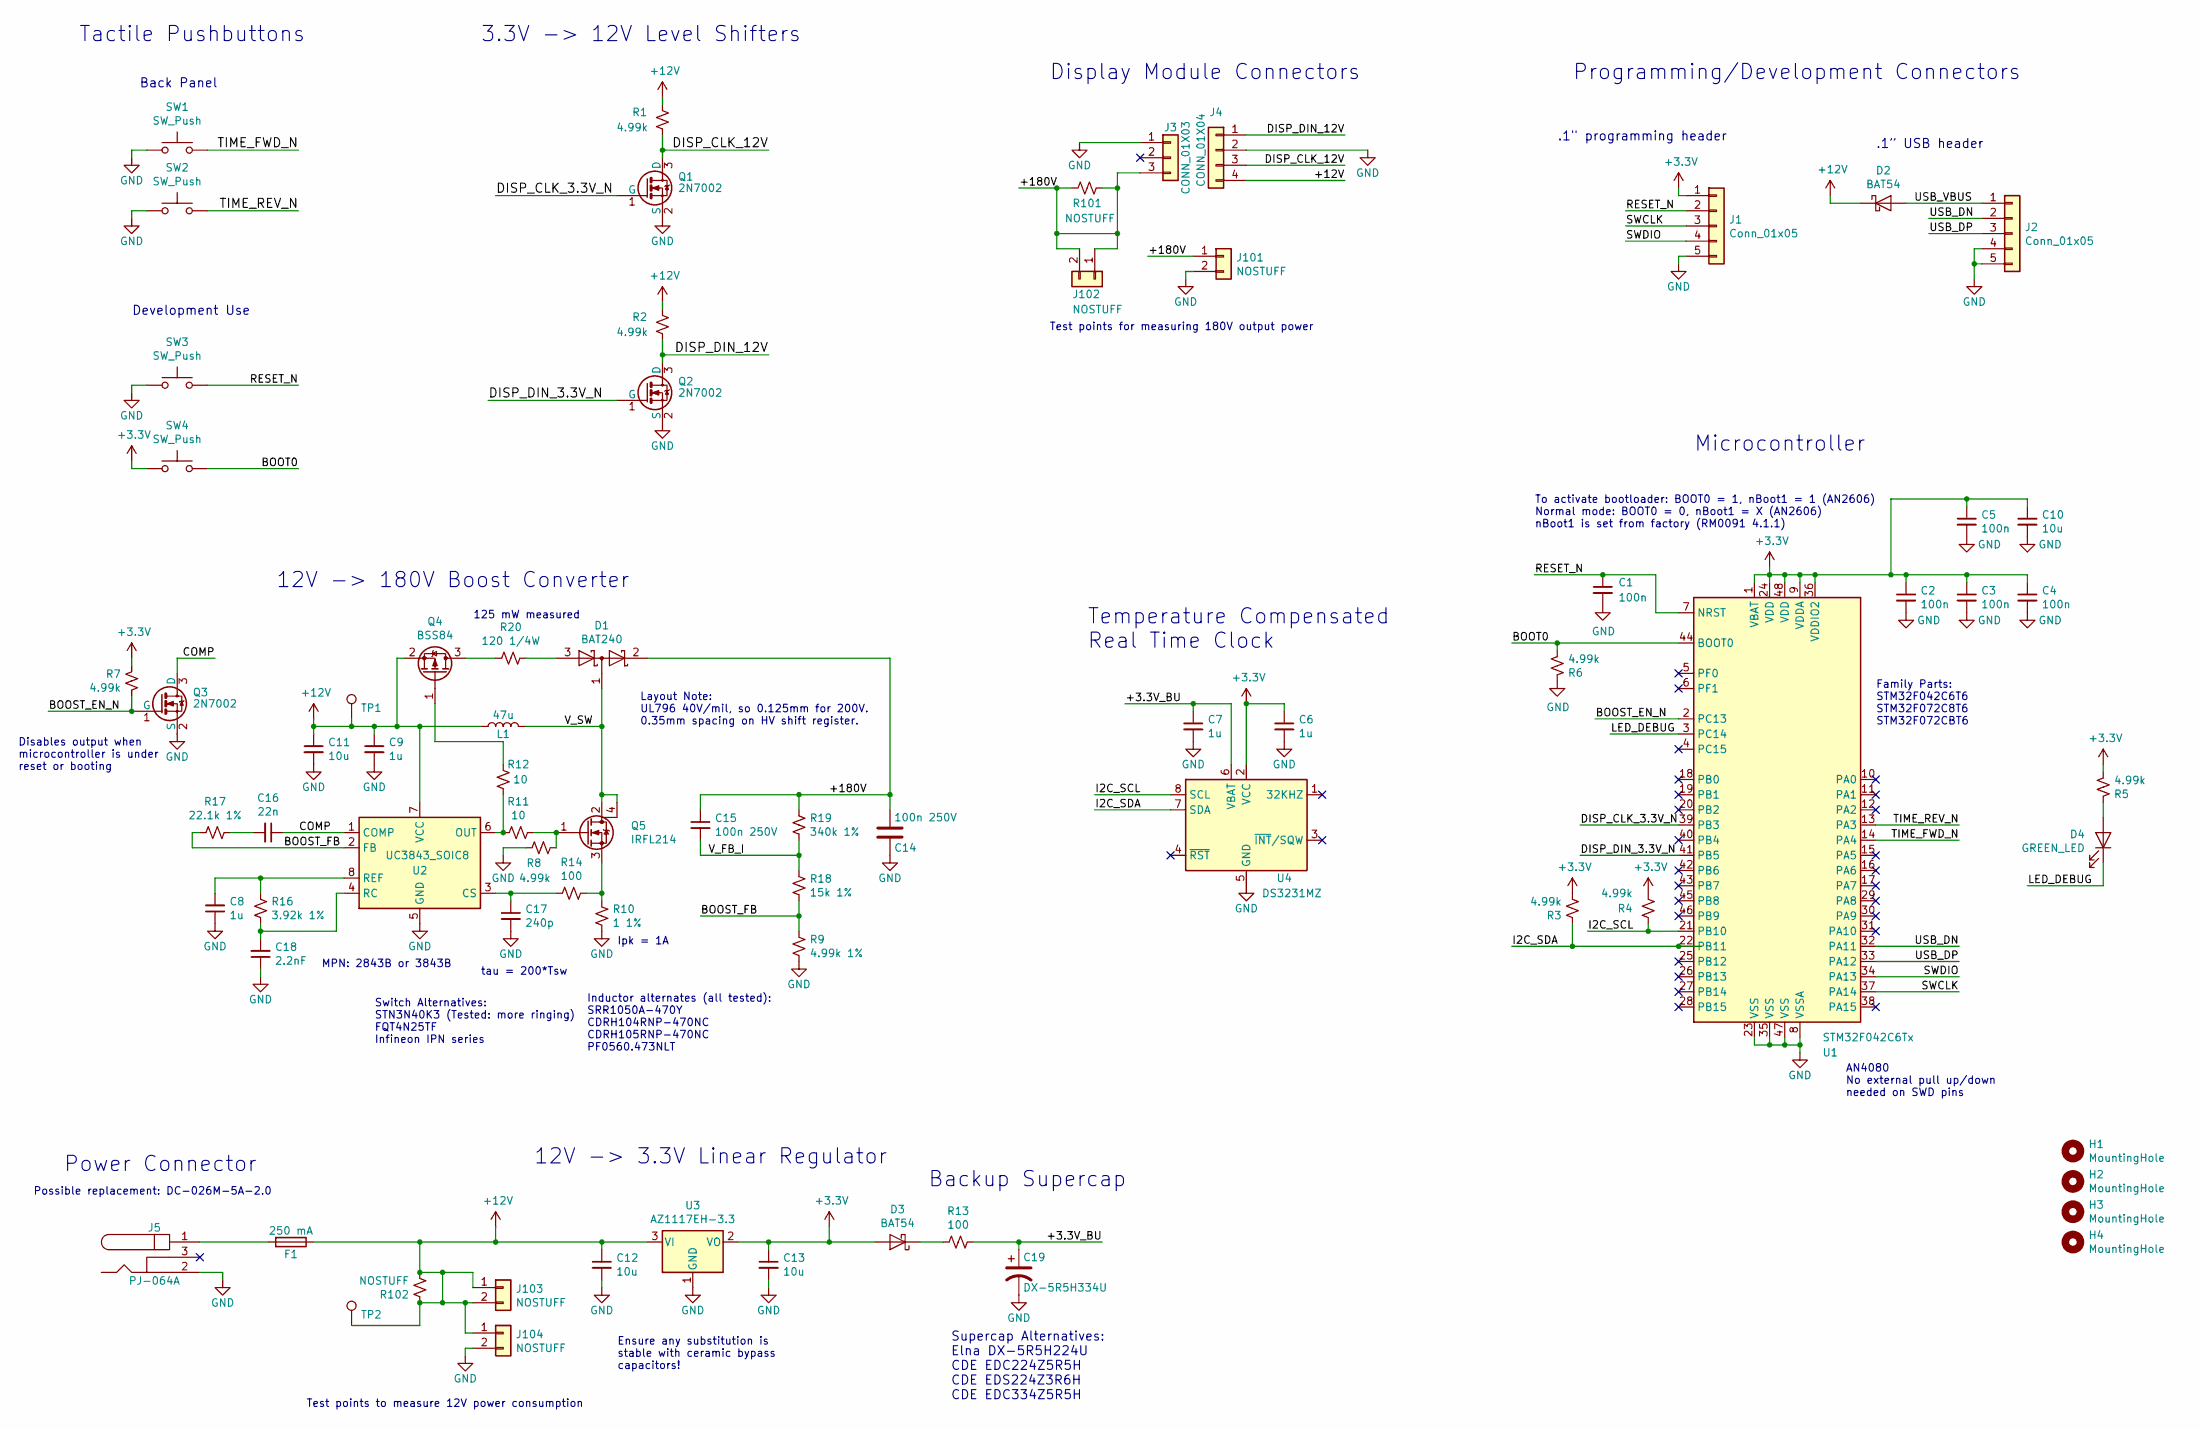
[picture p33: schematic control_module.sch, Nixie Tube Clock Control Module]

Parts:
C1, C2, C3, C4, C5: 100n; C_0805_2012Metric
C6, C7, C8, C9: 1u; C_0805_2012Metric
C10, C11, C12, C13: 10u; C_0805_2012Metric
C14, C15: 100n 250V; C_1206_3216Metric
C16: 22n; C_0805_2012Metric
C17: 240p; C_0805_2012Metric
C18: 2.2nF; C_0805_2012Metric
C19: DX-5R5H334U; EEC-S0HD334H
D1: BAT240; SOT-23
D2, D3: BAT54; D_SOD-123
D4: GREEN_LED; LED_0805_2012Metric
F1: 250 mA; Fuse_1206_3216Metric_Pad1.42x1.75mm_HandSolder
H1, H2, H3, H4: MountingHole; MountingHole_2.2mm_M2
J1, J2: Conn_01x05; PinHeader_1x05_P2.54mm_Vertical_NoSilk
J3: CONN_01X03; PinHeader_1x03_P2.54mm_Vertical
J4: CONN_01X04; PinHeader_1x04_P2.54mm_Vertical
J5: PJ-064A; PJ-064X
J101, J102, J103, J104: NOSTUFF; PinHeader_1x02_P2.54mm_Vertical
L1: 47u; L_TDK_SLF10145; Part Number 74404064221
Q1, Q2, Q3: 2N7002; SOT-23
Q4: BSS84; SOT-23
Q5: IRFL214; SOT-223
R1, R2, R3, R4, R5, R6, R7, R8: 4.99k; R_0805_2012Metric
R9: 4.99k 1%; R_0805_2012Metric
R10: 1 1%; R_0805_2012Metric
R11, R12: 10; R_0805_2012Metric
R13, R14: 100; R_0805_2012Metric
R16: 3.92k 1%; R_0805_2012Metric
R17: 22.1k 1%; R_0805_2012Metric
R18: 15k 1%; R_1206_3216Metric
R19: 340k 1%; R_1206_3216Metric
R20: 120 1/4W; R_1206_3216Metric
R101, R102: NOSTUFF; R_0805_2012Metric
SW1, SW2: SW_Push; SW_PUSH_6mm_H4.3mm
SW3, SW4: SW_Push; SW_SPST_TL3342
TP1, TP2: TestPoint; TestPoint_Pad_D1.0mm
U1: STM32F042C6Tx; LQFP-48_7x7mm_P0.5mm
U2: UC3843_SOIC8; SOIC-8_3.9x4.9mm_P1.27mm
U3: AZ1117EH-3.3; SOT-223-3_TabPin2
U4: DS3231MZ; SOIC-8_3.9x4.9mm_P1.27mm

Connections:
+3V3: C2.1, C3.1, C4.1, C5.1, C6.1, C10.1, C13.1, D3.2 (A), J1.1, R3.2, R4.2, R5.2, R7.1, SW4.1, U1.1 (VBAT), U1.9 (VDDA), U1.24 (VDD), U1.36 (VDDIO2), U1.48 (VDD), U3.2 (VO), U4.2 (VCC)
+12V: C9.1, C11.1, C12.1, D2.1 (K), F1.1, J4.4, J103.1, J103.2, J104.1, L1.1, Q4.2 (S), R1.2, R2.2, R102.1, R102.2, TP1.1, TP2.1, U2.7 (VCC), U3.3 (VI)
/+3.3V_BU: C7.1, C19.1, R13.1, U4.6 (VBAT)
/+180V: C14.2, C15.1, D1.2 (K), J3.3, J101.1, J102.1, J102.2, R19.1, R101.1, R101.2
/BOOST_EN_N: Q3.1 (G), R7.2, U1.2 (PC13)
/BOOST_FB: R9.1, R17.2, R18.2, U2.2 (FB)
/BOOT0: R6.2, SW4.2, U1.44 (BOOT0)
/COMP: C16.1, Q3.3 (D), U2.1 (COMP)
/DISP_CLK_3.3V_N: Q1.1 (G), U1.39 (PB3)
/DISP_CLK_12V: J4.3, Q1.3 (D), R1.1
/DISP_DIN_3.3V_N: Q2.1 (G), U1.41 (PB5)
/DISP_DIN_12V: J4.1, Q2.3 (D), R2.1
/I2C_SCL: R4.1, U1.21 (PB10), U4.8 (SCL)
/I2C_SDA: R3.1, U1.22 (PB11), U4.7 (SDA)
/LED_DEBUG: D4.1 (K), U1.3 (PC14)
/RESET_N: C1.1, J1.2, SW3.2, U1.7 (NRST)
/SWCLK: J1.3, U1.37 (PA14)
/SWDIO: J1.4, U1.34 (PA13)
/TIME_FWD_N: SW1.2, U1.14 (PA4)
/TIME_REV_N: SW2.2, U1.13 (PA3)
/USB_DN: J2.2, U1.32 (PA11)
/USB_DP: J2.3, U1.33 (PA12)
/USB_VBUS: D2.2 (A), J2.1
/V_FB_I: C15.2, R18.1, R19.2
/V_SW: D1.1 (common), L1.2, Q5.2 (D), Q5.4 (D)
GND: C1.2, C2.2, C3.2, C4.2, C5.2, C6.2, C7.2, C8.1, C9.2, C10.2, C11.2, C12.2, C13.2, C14.1, C17.2, C18.1, C19.2, J1.5, J2.4, J2.5, J3.1, J4.2, J5.2, J101.2, J104.2, Q1.2 (S), Q2.2 (S), Q3.2 (S), R6.1, R8.2, R9.2, R10.2, SW1.1, SW2.1, SW3.1, U1.8 (VSSA), U1.23 (VSS), U1.35 (VSS), U1.47 (VSS), U2.5 (GND), U3.1 (GND), U4.5 (GND)
unnamed: C8.2, R16.2, U2.8 (REF)
unnamed: C16.2, R17.1
unnamed: C17.1, R14.2, U2.3 (CS)
unnamed: C18.2, R16.1, U2.4 (RC)
unnamed: D1.3 (A), R20.1
unnamed: D3.1 (K), R13.2
unnamed: D4.2 (A), R5.1
unnamed: F1.2, J5.1
unnamed: Q4.1 (G), R12.2
unnamed: Q4.3 (D), R20.2
unnamed: Q5.1 (G), R8.1, R11.1
unnamed: Q5.3 (S), R10.1, R14.1
unnamed: R11.2, R12.1, U2.6 (OUT)

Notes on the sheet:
Supercap Alternatives: Elna DX-5R5H224U CDE EDC224Z5R5H CDE EDS224Z3R6H CDE EDC334Z5R5H
Display Module Connectors
Back Panel
.1" programming header
Layout Note: UL796 40V/mil, so 0.125mm for 200V. 0.35mm spacing on HV shift register.
tau = 200*Tsw
Ipk = 1A
Possible replacement: DC-026M-5A-2.0
Switch Alternatives: STN3N40K3 (Tested: more ringing) FQT4N25TF Infineon IPN series
.1” USB header
To activate bootloader: BOOT0 = 1, nBoot1 = 1 (AN2606) Normal mode: BOOT0 = 0, nBoot1 = X (AN2606) nBoot1 is set from factory (RM0091 4.1.1)
AN4080 No external pull up/down needed on SWD pins
125 mW measured
Ensure any substitution is stable with ceramic bypass capacitors!
MPN: 2843B or 3843B
Family Parts: STM32F042C6T6 STM32F072C8T6 STM32F072CBT6
Development Use
Test points for measuring 180V output power
Test points to measure 12V power consumption
12V -> 180V Boost Converter
12V -> 3.3V Linear Regulator
3.3V -> 12V Level Shifters
Tactile Pushbuttons
Temperature Compensated Real Time Clock
Backup Supercap
Programming/Development Connectors
Microcontroller
Disables output when microcontroller is under reset or booting
Power Connector
Inductor alternates (all tested): SRR1050A-470Y CDRH104RNP-470NC CDRH105RNP-470NC PF0560.473NLT

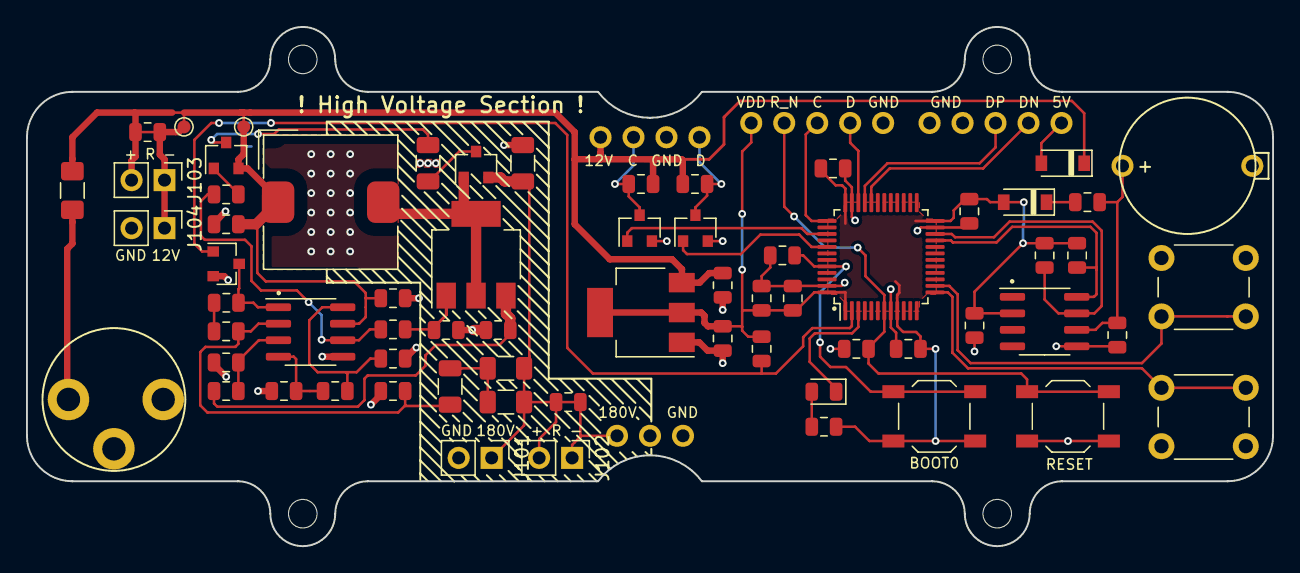
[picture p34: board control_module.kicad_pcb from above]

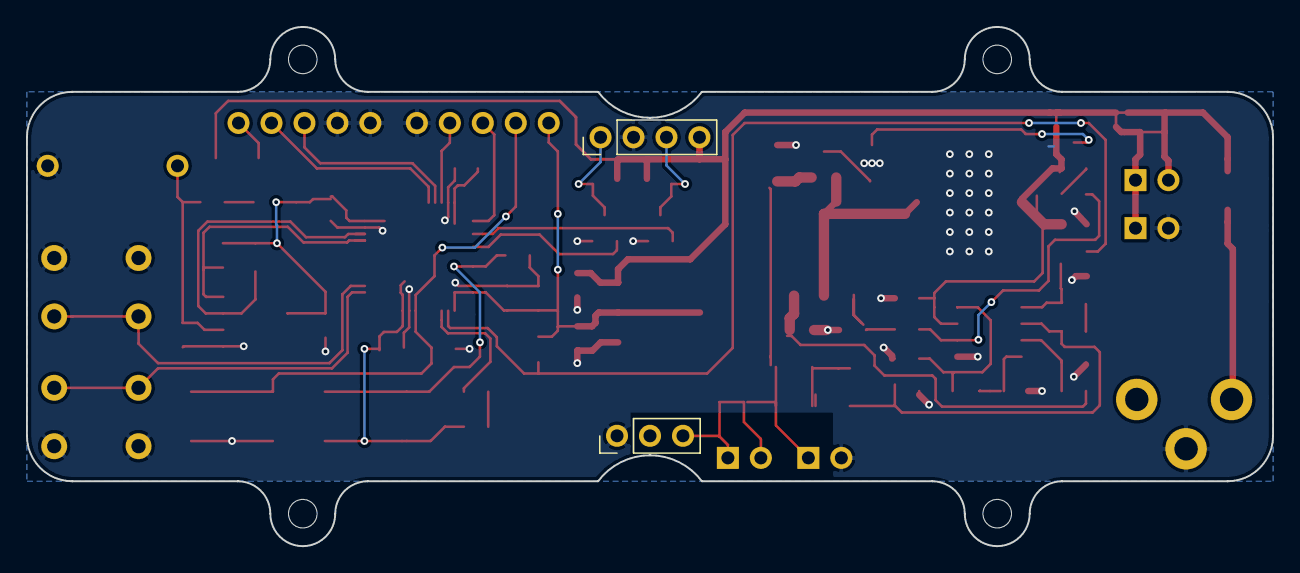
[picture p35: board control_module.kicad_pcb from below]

Board: 2 copper layers, 96.0 x 40.0 mm, 74 parts (2 on the bottom side), 39 nets.

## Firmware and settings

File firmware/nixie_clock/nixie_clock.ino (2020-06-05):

#include <SPI.h>
#include <Wire.h>
#include "RTClib.h"

// UI times
#define TEST_PATTERN_TRIGGER_DELAY 2000UL // Time to triggger test pattern, ms
#define TEST_PATTERN_DELAY 250UL // Time to display each frame in test pattern, ms
#define MAIN_LOOP_DELAY 20UL // Main loop time, ms
#define TIME_SET_FAST_DELAY 500UL // Time before time starts incrementing/decrementing rapidly, ms

// UI states
uint32_t time_fwd_time_pressed = 0;
uint32_t time_fwd_last_state = 0;

uint32_t time_rev_time_pressed = 0;
uint32_t time_rev_last_state = 0;

// Signal assignments from control PCB
#define DISPLAY_CLOCK_N PB3
#define DISPLAY_DATA_N PB5
#define SPI_MISO_DUMMY PB4
#define BOOST_EN_N PC13
#define LED_DEBUG_N PC14
#define TIME_FWD_N PA4
#define TIME_REV_N PA3
#define I2C_SDA PB11
#define I2C_SCL PB10

// Signal Assignments from display PCB
const uint8_t tube1[] = {31-20, 31-19, 31-21};
const uint8_t tube2[] = {31-23, 31-22, 31-25, 31-26, 31-31, 31-30, 31-29, 31-28, 31-27, 31-24};
const uint8_t tube3[] = {31-13, 31-11, 31-10, 31-6, 31-1, 31-0};
const uint8_t tube4[] = {31-2, 31-16, 31-15, 31-14, 31-9, 31-8, 31-7, 31-5, 31-4, 31-3};

#define DISPLAY_LEFT_COMMA (1<<(31-18))
#define DISPLAY_RIGHT_COMMA (1<<(31-12))
#define DISPLAY_NO_COMMA 0

// DS3231 instance
RTC_DS3231 rtc_ds3231;

void setup() {

  // Initialize GPIOs
  digitalWrite(BOOST_EN_N, HIGH);
  pinMode(BOOST_EN_N, OUTPUT);
  
  digitalWrite(DISPLAY_CLOCK_N, HIGH);
  digitalWrite(DISPLAY_DATA_N, HIGH);
  pinMode(DISPLAY_CLOCK_N, OUTPUT);
  pinMode(DISPLAY_DATA_N, OUTPUT);

  pinMode(TIME_FWD_N, INPUT_PULLUP);
  pinMode(TIME_REV_N, INPUT_PULLUP);

  digitalWrite(LED_DEBUG_N, HIGH);
  pinMode(LED_DEBUG_N, OUTPUT);

  // Need to initalize SPI first so we can continuously turn off
  // the display while the boost converter starts up.
  SPI = SPIClass(DISPLAY_DATA_N, SPI_MISO_DUMMY, DISPLAY_CLOCK_N);
  SPI.begin();
  SPI.beginTransaction(SPISettings(1E6,LSBFIRST,SPI_MODE0));

  // Turning the boost converter on seems to put garbage in the 
  // shift register, so continuously write (inverted) zeros to it.
  digitalWrite(LED_DEBUG_N, LOW);
  unsigned long tStart = millis();
  SPI.transfer16(0xFFFF);
  SPI.transfer16(0xFFFF);
  digitalWrite(BOOST_EN_N, LOW); // Enable the boost converter
  while(millis()-tStart < 200)
  {
    SPI.transfer16(0xFFFF);
    SPI.transfer16(0xFFFF);
  }
  digitalWrite(LED_DEBUG_N, HIGH);

  // Start I2C on alternate pins *before* starting the DS3231 RTC
  Wire.setSDA(I2C_SDA);
  Wire.setSCL(I2C_SCL);
  Wire.begin();

  // Start the DS3231 RTC
  if (!rtc_ds3231.begin())
  {
    error_handler(1);
  }
}

void loop() 
{
  // Record start time of the main loop
  unsigned long loop_start = millis();

  // Poll the current state of the buttons
  uint32_t time_fwd_current_state = !digitalRead(TIME_FWD_N);
  uint32_t time_rev_current_state = !digitalRead(TIME_REV_N);


  // If button was just pressed, increment/decrement the time
  if(time_fwd_current_state && !time_fwd_last_state)
  {
    increment_time();
  }
  // If button is being held...
  if(time_fwd_current_state && time_fwd_last_state)
  {
    // Keep track of how long the button has been pressed, 
    // while preventing any odd behavior from overflow
    if (time_fwd_time_pressed <= TIME_SET_FAST_DELAY+TEST_PATTERN_TRIGGER_DELAY)
    {
      time_fwd_time_pressed += MAIN_LOOP_DELAY;
    }

    // If the button has been pressed for longer than TIME_SET_FAST_DELAY, 
    // start incrementing/decrementing time on every iteration of this loop
    if (time_fwd_time_pressed >= TIME_SET_FAST_DELAY)
    {
      increment_time();
    }
  }
  // If not currently pressed, reset time pressed to zero
  if(!time_fwd_current_state)
  {
    time_fwd_time_pressed = 0;
  }


  // If button was just pressed, increment/decrement the time
  if(time_rev_current_state && !time_rev_last_state)
  {
    decrement_time();
  }
  // If button is being held...
  if(time_rev_current_state && time_rev_last_state)
  {
    // Keep track of how long the button has been pressed, 
    // while preventing any odd behavior from overflow
    if (time_rev_time_pressed <= TIME_SET_FAST_DELAY+TEST_PATTERN_TRIGGER_DELAY)
    {
      time_rev_time_pressed += MAIN_LOOP_DELAY;
    }

    // If the button has been pressed for longer than TIME_SET_FAST_DELAY, 
    // start incrementing/decrementing time on every iteration of this loop
    if (time_rev_time_pressed >= TIME_SET_FAST_DELAY)
    {
      decrement_time();
    }
  }
  // If not currently pressed, reset time pressed to zero
  if(!time_rev_current_state)
  {
    time_rev_time_pressed = 0;
  }

  // If both buttons have been pressed for longer than TEST_PATTERN_TRIGGER_DELAY,
  // show the test pattern
  if((time_rev_time_pressed >= TEST_PATTERN_TRIGGER_DELAY) && (time_fwd_time_pressed >= TEST_PATTERN_TRIGGER_DELAY))
  {
    show_test_pattern(TEST_PATTERN_DELAY);
  }


  // Update the display
  DateTime now = rtc_ds3231.now();
  updateDisplay(now.hour(),now.minute(),0);


  // Save the last state of the buttons
  time_fwd_last_state = time_fwd_current_state;
  time_rev_last_state = time_rev_current_state;

  // Delay for the rest of the MAIN_LOOP_DELAY, if any.
  // If millis was about to overflow, loop_start+MAIN_LOOP_DELAY will be a small number, 
  // thus immediately triggering without the proper delay, which won't cause it to lock up.
  // If loop_start + MAIN_LOOP_DELAY is max unsigned long, "<" should still cause the loop 
  // to continue. I'm pretty sure this won't lock up even under overflow conditions.
  while(millis() < (loop_start + MAIN_LOOP_DELAY))
  {
    ;
  }
}

void increment_time()
{
  // Get the time from the DS3231 RTC
  DateTime now = rtc_ds3231.now();
  uint32_t current_hour = now.hour();
  uint32_t current_minute = now.minute();

  // Increment the time
  if(current_minute == 59)
    {
      if(current_hour == 23)
      {
        current_hour = 0;
        current_minute = 0;
      }
      else
      {
        current_hour++;
        current_minute = 0;
      }
    }
    else
    {
      current_minute++;
    }
    
  // Write the incremented time back to the DS3231 RTC
  rtc_ds3231.adjust(DateTime(2000, 1, 1, current_hour, current_minute, 0));
}

void decrement_time()
{
  // Get the time from the DS3231 RTC
  DateTime now = rtc_ds3231.now();
  uint32_t current_hour = now.hour();
  uint32_t current_minute = now.minute();

  // Decrement the time
  if(current_minute == 0)
  {
    if(current_hour == 0)
    {
      current_hour = 23;
      current_minute = 59;
    }
    else
    {
      current_hour--;
      current_minute = 59;
    }
  }
  else
  {
    current_minute--;
  }

  // Write the decremented time back to the DS3231 RTC
  rtc_ds3231.adjust(DateTime(2000, 1, 1, current_hour, current_minute, 0));
}


// Sends 32 bit buffer to the display
void send_display_buffer(uint32_t tx_buf)
{
  SPI.transfer16((uint16_t) tx_buf);
  SPI.transfer16((uint16_t) (tx_buf>>16));
}


void updateDisplay(uint32_t hour, uint32_t minute, uint32_t mode24hr)
{
  uint32_t tx_buf = 0;

  // 24 hour mode is easy
  if (mode24hr)
  {
    tx_buf = ~((1<<tube1[hour/10])|(1<<tube2[hour%10])|(1<<tube3[minute/10])|(1<<tube4[minute%10]));
  }
  else
  {
    // AM/PM is super awkward. Maybe there's a cleaner way to do this.
    if (hour == 0)
    {
      tx_buf = ~((1<<tube1[1])|(1<<tube2[2])|(1<<tube3[minute/10])|(1<<tube4[minute%10]));
    }
    else if (hour == 12)
    {
      tx_buf = ~((1<<tube1[1])|(1<<tube2[2])|(1<<tube3[minute/10])|(1<<tube4[minute%10])|DISPLAY_LEFT_COMMA);
    }
    else if (hour > 12)
    {
      if((hour-12)/10 == 0)
      {
        tx_buf = ~((1<<tube2[(hour-12)%10])|(1<<tube3[minute/10])|(1<<tube4[minute%10])|DISPLAY_LEFT_COMMA);
      }
      else
      {
        tx_buf = ~((1<<tube1[(hour-12)/10])|(1<<tube2[(hour-12)%10])|(1<<tube3[minute/10])|(1<<tube4[minute%10])|DISPLAY_LEFT_COMMA);
      }
    }
    else
    {
      if (hour/10 == 0)
      {
        tx_buf = ~((1<<tube2[hour%10])|(1<<tube3[minute/10])|(1<<tube4[minute%10]));
      }
      else
      {
        tx_buf = ~((1<<tube1[hour/10])|(1<<tube2[hour%10])|(1<<tube3[minute/10])|(1<<tube4[minute%10]));
      }
    }
  }
  
  send_display_buffer(tx_buf);
}


void show_test_pattern(uint32_t test_pattern_delay)
{
  for(uint32_t digit = 0; digit <= 2; digit++)
    {
      uint32_t tx_buf = ~((1<<tube1[digit])|(1<<tube2[0])|(1<<tube3[0])|(1<<tube4[0]));
      send_display_buffer(tx_buf);
      delay(test_pattern_delay);
    }
    for(uint32_t digit = 0; digit <= 9; digit++)
    {
      uint32_t tx_buf = ~((1<<tube1[0])|(1<<tube2[digit])|(1<<tube3[0])|(1<<tube4[0]));
      send_display_buffer(tx_buf);
      delay(test_pattern_delay);
    }
    for(uint32_t digit = 0; digit <= 5; digit++)
    {
      uint32_t tx_buf = ~((1<<tube1[0])|(1<<tube2[0])|(1<<tube3[digit])|(1<<tube4[0]));
      send_display_buffer(tx_buf);
      delay(test_pattern_delay);
    }
    for(uint32_t digit = 0; digit <= 9; digit++)
    {
      uint32_t tx_buf = ~((1<<tube1[0])|(1<<tube2[0])|(1<<tube3[0])|(1<<tube4[digit]));
      send_display_buffer(tx_buf);
      delay(test_pattern_delay);
    }

    uint32_t disp0000_left_comma = ~((1<<tube1[0])|(1<<tube2[0])|(1<<tube3[0])|(1<<tube4[0])|DISPLAY_LEFT_COMMA);
    send_display_buffer(disp0000_left_comma);
    delay(test_pattern_delay);

    uint32_t disp0000_right_comma = ~((1<<tube1[0])|(1<<tube2[0])|(1<<tube3[0])|(1<<tube4[0])|DISPLAY_RIGHT_COMMA);
    send_display_buffer(disp0000_right_comma);
    delay(test_pattern_delay);
}

void error_handler(uint32_t n)
{
  digitalWrite(LED_DEBUG_N, HIGH);
  while(1)
  {
    for(uint32_t i = 0; i < n; i++)
    {
      digitalWrite(LED_DEBUG_N, LOW);
      delay(75);
      digitalWrite(LED_DEBUG_N, HIGH);
      delay(75);
    }
    delay(1000);
  }
}

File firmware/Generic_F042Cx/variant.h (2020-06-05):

/*
 *******************************************************************************
 * Copyright (c) 2019, STMicroelectronics
 * All rights reserved.
 *
 * This software component is licensed by ST under BSD 3-Clause license,
 * the "License"; You may not use this file except in compliance with the
 * License. You may obtain a copy of the License at:
 *                        opensource.org/licenses/BSD-3-Clause
 *
 *******************************************************************************
 */

#ifndef _VARIANT_ARDUINO_STM32_
#define _VARIANT_ARDUINO_STM32_

#ifdef __cplusplus
extern "C" {
#endif // __cplusplus

/*----------------------------------------------------------------------------
 *        Pins
 *----------------------------------------------------------------------------*/

// Define pin names to match digital pin number --> Dx
// It could be used with preprocessor tests (e.g. #if PXn == 3)
// so an enum will not work.
// !!!
// !!! Copy the digitalPin[] array from the variant.cpp
// !!! and remove all '_': PX_n --> PXn
// !!! For NC, comment the line to warn x pin number is NC
// !!! // x is NC
// !!! For duplicated pin name, comment the line to warn x pin number
// !!! is PXn which is already defined with y pin number
// !!! // x is PXn (y)
// !!! Ex:
// !!! ...
// !!! #define PA4  20 // A14 <-- if NUM_ANALOG_FIRST not defined
// !!! or
// !!! #define PA4  A14 // 20 <-- if NUM_ANALOG_FIRST defined
// !!! #define PB4  21
// !!! #define PB5  22
// !!! #define PB3  23
// !!! // 24 is PA4 (20)
// !!! // 25 is PB4 (21)
// !!! #define PA2  26 // A15 <-- if NUM_ANALOG_FIRST not defined
// !!! or
// !!! #define PA2  A15 // 26 <-- if NUM_ANALOG_FIRST defined
// !!! ...


// Lifted from bluepill definition
#define PB9  0
#define PB8  1
#define PB7  2
#define PB6  3
#define PB5  4
#define PB4  5
#define PB3  6
#define PA15 7
#define PA12 8  // USB DP
#define PA11 9  // USB DM
#define PA10 10
#define PA9  11
#define PA8  12
#define PB15 13
#define PB14 14
#define PB13 15
#define PB12 16
#define PC13 17
#define PC14 18
#define PC15 19
#define PA0  20 // A0
#define PA1  21 // A1
#define PA2  22 // A2
#define PA3  23 // A3
#define PA4  24 // A4
#define PA5  25 // A5
#define PA6  26 // A6
#define PA7  27 // A7
#define PB0  28 // A8
#define PB1  29 // A9
#define PB10 30
#define PB11 31
// Other
#define PB2  32 //
#define PA13 33 // SWDI0
#define PA14 34 // SWCLK

// This must be a literal
// It is used with preprocessor tests (e.g. #if NUM_DIGITAL_PINS > 3)
// so an enum will not work.
#define NUM_DIGITAL_PINS        35

// Needs to be verified. Assumed same as STM32F103C8xTx
#define NUM_ANALOG_INPUTS       10
#define NUM_ANALOG_FIRST        20



// Below SPI and I2C definitions already done in the core
// Could be redefined here if differs from the default one
// SPI Definitions
//#define PIN_SPI_SS              10 // Default for Arduino connector compatibility
//#define PIN_SPI_MOSI            11 // Default for Arduino connector compatibility
//#define PIN_SPI_MISO            12 // Default for Arduino connector compatibility
//#define PIN_SPI_SCK             13 // Default for Arduino connector compatibility

// I2C Definitions
//#define PIN_WIRE_SDA            14 // Default for Arduino connector compatibility
//#define PIN_WIRE_SCL            15 // Default for Arduino connector compatibility

// I2C timing definitions (optional), avoid time spent to compute if defined
// * I2C_TIMING_SM for Standard Mode (100kHz)
// * I2C_TIMING_FM for Fast Mode (400kHz)
// * I2C_TIMING_FMP for Fast Mode Plus (1000kHz)
//#define I2C_TIMING_SM           0x00000000
//#define I2C_TIMING_FM           0x00000000
//#define I2C_TIMING_FMP          0x00000000

// Timer Definitions (optional)
// Use TIM6/TIM7 when possible as servo and tone don't need GPIO output pin
#define TIMER_TONE              TIM3
#define TIMER_SERVO             TIM2

// UART Definitions
// Define here Serial instance number to map on Serial generic name
#define SERIAL_UART_INSTANCE    1 //ex: 2 for Serial2 (USART2)
// DEBUG_UART could be redefined to print on another instance than 'Serial'
//#define DEBUG_UART              ((USART_TypeDef *) U(S)ARTX) // ex: USART3
// DEBUG_UART baudrate, default: 9600 if not defined
//#define DEBUG_UART_BAUDRATE     x
// DEBUG_UART Tx pin name, default: the first one found in PinMap_UART_TX for DEBUG_UART
//#define DEBUG_PINNAME_TX        PX_n // PinName used for TX

// Default pin used for 'Serial' instance (ex: ST-Link)
// Mandatory for Firmata
#define PIN_SERIAL_RX           PA10
#define PIN_SERIAL_TX           PA9

// Optional PIN_SERIALn_RX and PIN_SERIALn_TX where 'n' is the U(S)ART number
// Used when user instanciate a hardware Serial using its peripheral name.
// Example: HardwareSerial mySerial(USART3);
// will use PIN_SERIAL3_RX and PIN_SERIAL3_TX if defined.
//#define PIN_SERIALn_RX          x // For U(S)ARTn RX
//#define PIN_SERIALn_TX          x // For U(S)ARTn TX
//#define PIN_SERIALLP1_RX        x // For LPUART1 RX
//#define PIN_SERIALLP1_TX        x // For LPUART1 TX

// SD card slot Definitions
// SD detect signal can be defined if required
//#define SD_DETECT_PIN           x
// SD Read/Write timeout, default value defined in STM32SD library
//#define SD_DATATIMEOUT          x

#ifdef __cplusplus
} // extern "C"
#endif
/*----------------------------------------------------------------------------
 *        Arduino objects - C++ only
 *----------------------------------------------------------------------------*/

#ifdef __cplusplus
// These serial port names are intended to allow libraries and architecture-neutral
// sketches to automatically default to the correct port name for a particular type
// of use.  For example, a GPS module would normally connect to SERIAL_PORT_HARDWARE_OPEN,
// the first hardware serial port whose RX/TX pins are not dedicated to another use.
//
// SERIAL_PORT_MONITOR        Port which normally prints to the Arduino Serial Monitor
//
// SERIAL_PORT_USBVIRTUAL     Port which is USB virtual serial
//
// SERIAL_PORT_LINUXBRIDGE    Port which connects to a Linux system via Bridge library
//
// SERIAL_PORT_HARDWARE       Hardware serial port, physical RX & TX pins.
//
// SERIAL_PORT_HARDWARE_OPEN  Hardware serial ports which are open for use.  Their RX & TX
//                            pins are NOT connected to anything by default.
#define SERIAL_PORT_MONITOR     Serial
#define SERIAL_PORT_HARDWARE    Serial1
#endif

#endif /* _VARIANT_ARDUINO_STM32_ */
